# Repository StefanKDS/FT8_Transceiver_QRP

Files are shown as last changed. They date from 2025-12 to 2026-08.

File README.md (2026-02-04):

# FT8 Transceiver

My QRP FT8 Transceiver is basded on a ATS20+ Receiver and on the FT8 project on the website https://www.elektronik-labor.de/HF/FT8QRP.html .

The new Firmware of the ATS20+ is based on the firmware from Goshante: https://github.com/goshante/ats20_ats_ex .  
The Firmware of the TX part is based on these project: https://www.elektronik-labor.de/HF/FT8QRP.html .
You can find the documentation of the TX code here: https://github.com/StefanKDS/FT8_Transceiver_QRP/blob/main/ATS_EX_FT8_TX/Documentation/FT8_TX_Documentation.pdf

I made modifications on both source codes.

Please note that the Microcontroller of the TX part has to be a Nano, not a Nano R4, because I use the comperator input D6 / D7. The Nano R4 don't has these input.

The PA is a 2W PA from China. For this use it's totally OK.
In the end of these document you can find pictures of all parts I bought.

## Overview:


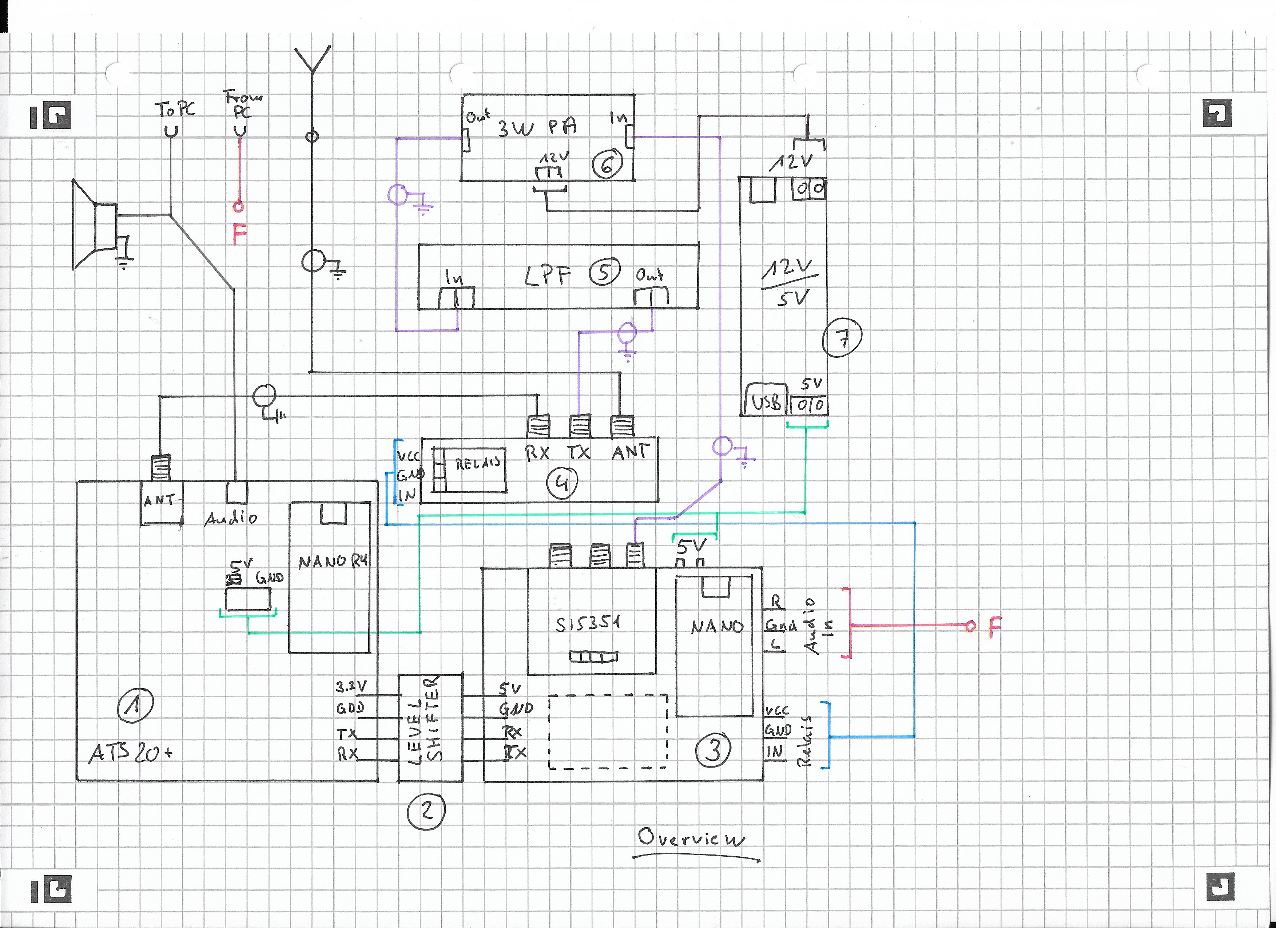
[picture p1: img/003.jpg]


## Description:

On the ATS20+ Board we have to make some small modifications:

- Replace the Arduino Nano with a Arduino Nano R4. The "old" Nano you can use for the TX part.
- Remove the battery
- Remove U1 (TP4056).
- Upload the fimrware in the folder ATS_EX.

## Details:
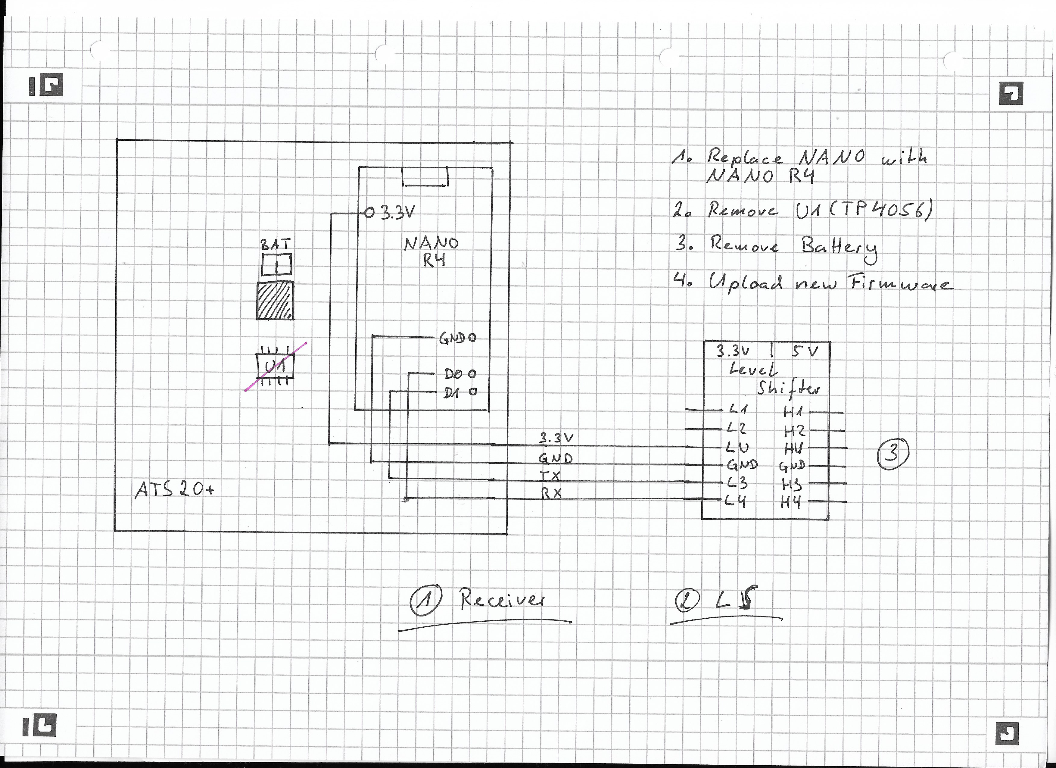
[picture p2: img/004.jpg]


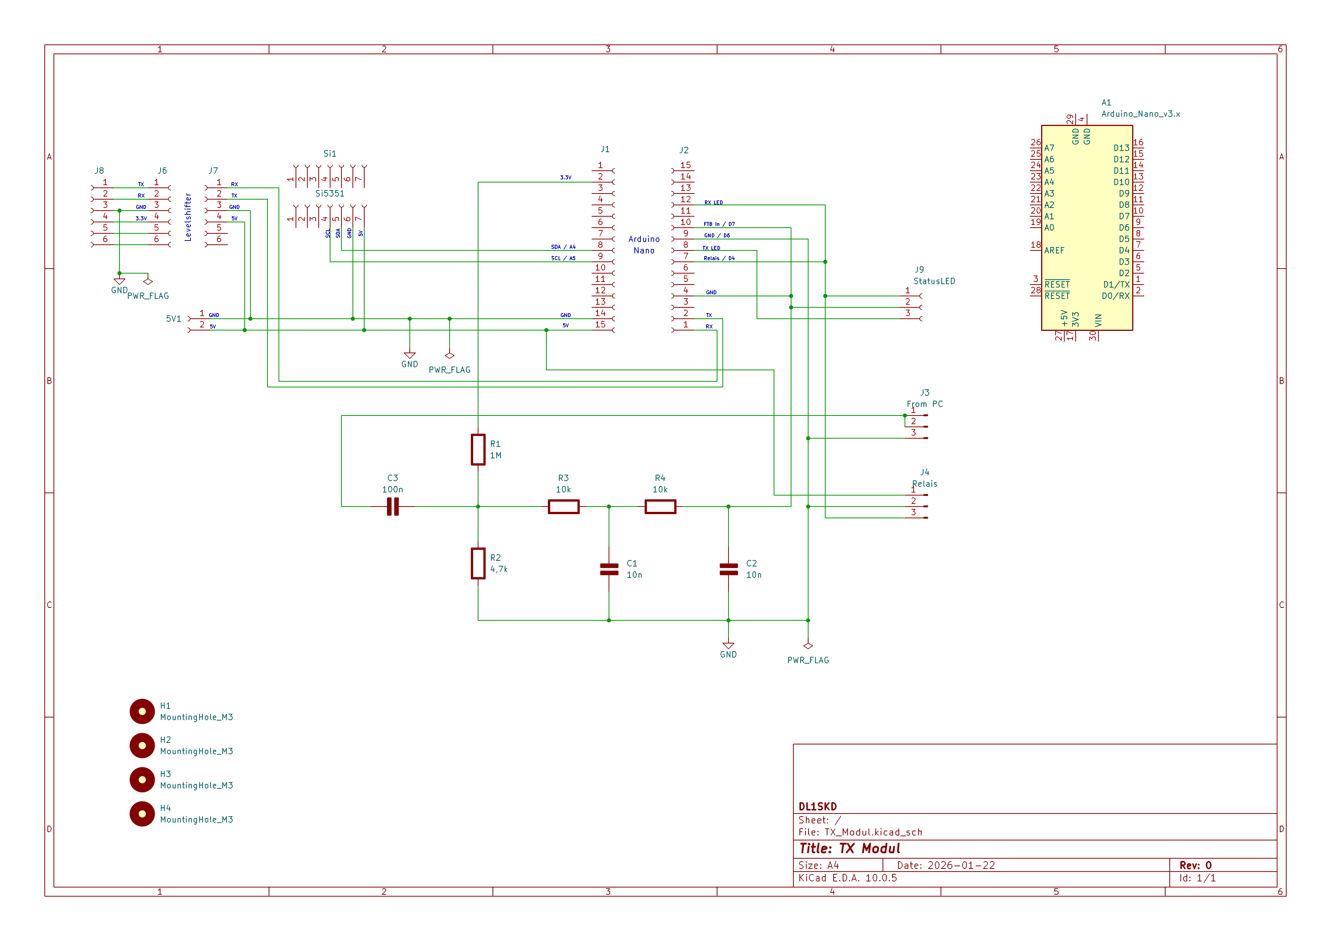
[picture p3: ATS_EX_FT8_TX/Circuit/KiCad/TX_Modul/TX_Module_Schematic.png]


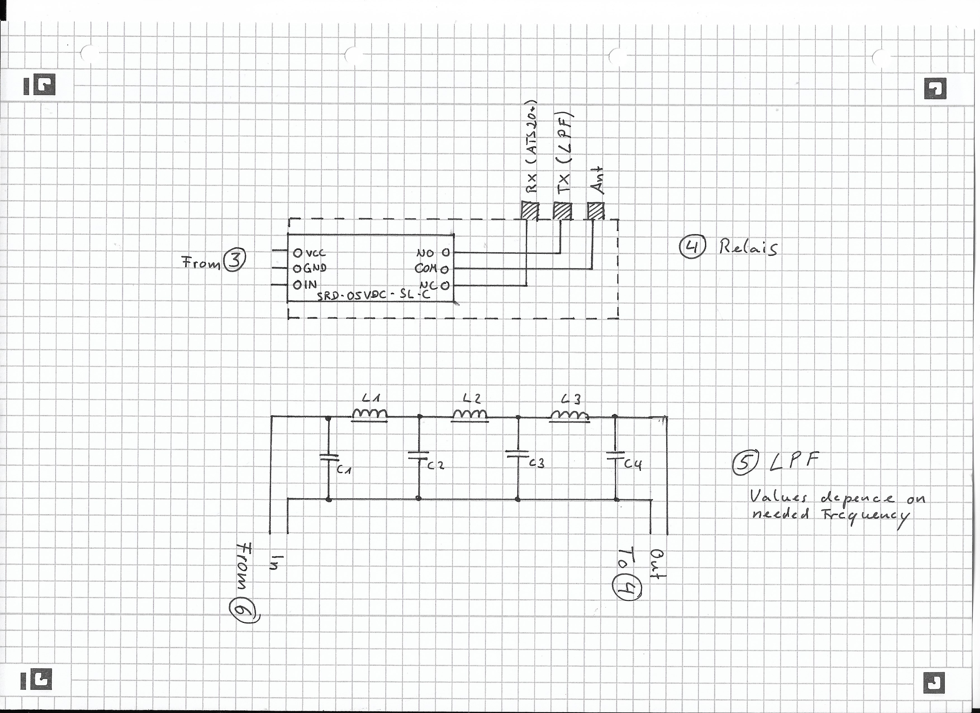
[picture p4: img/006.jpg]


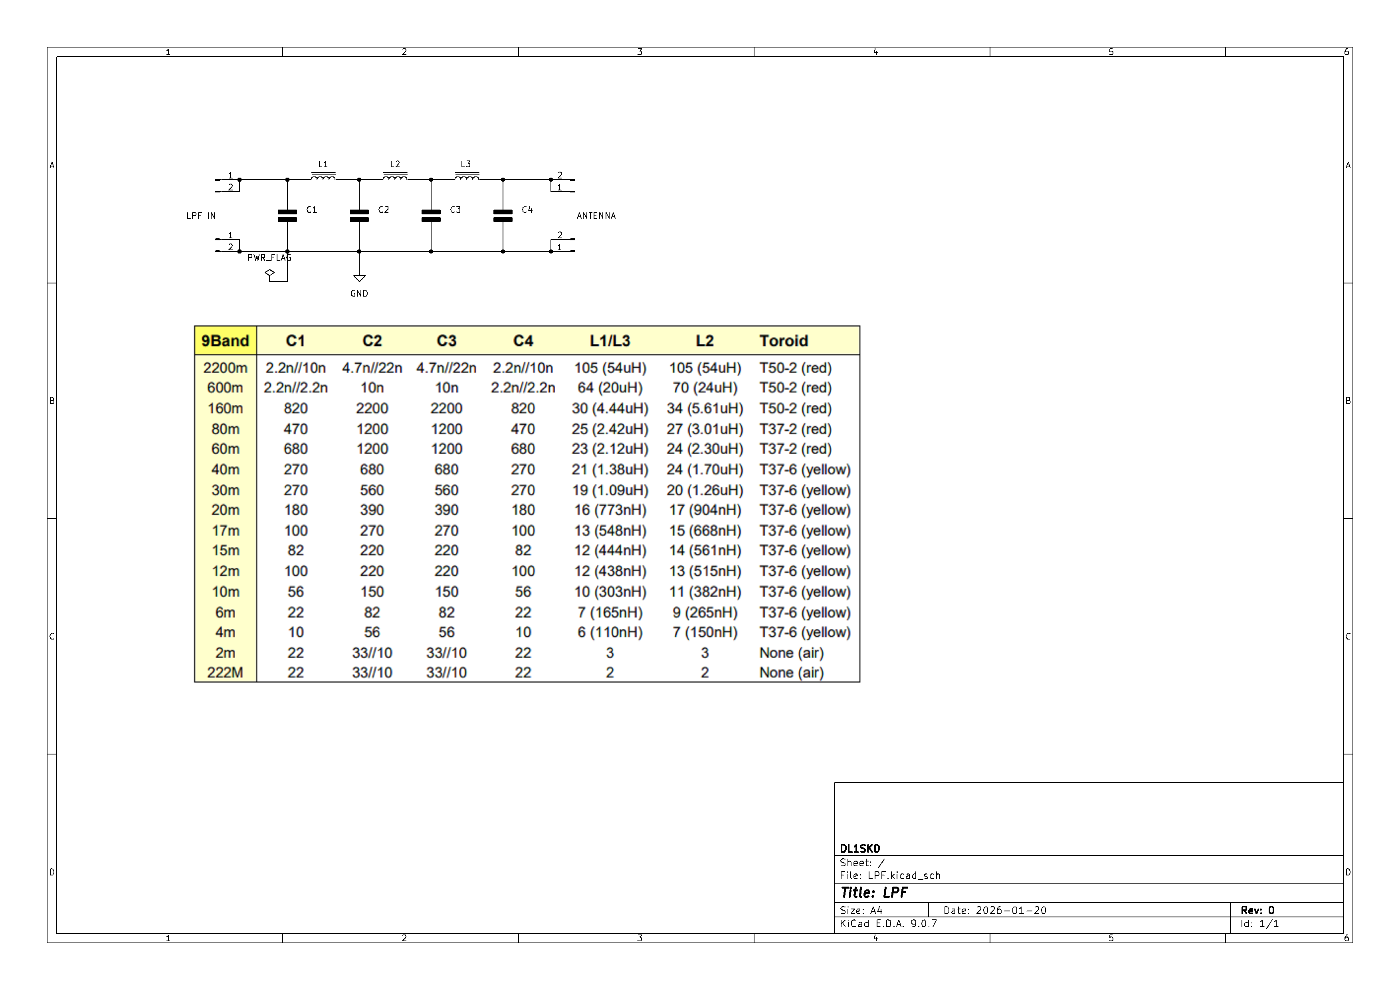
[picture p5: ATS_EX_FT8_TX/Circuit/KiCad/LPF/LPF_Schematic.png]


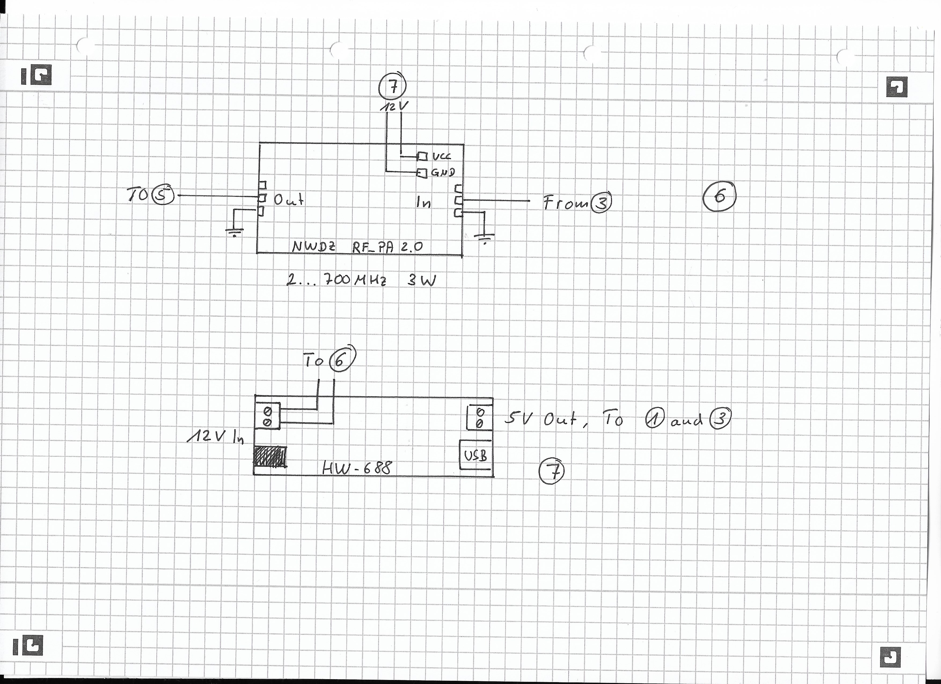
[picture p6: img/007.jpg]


## Used parts:
ATS20+
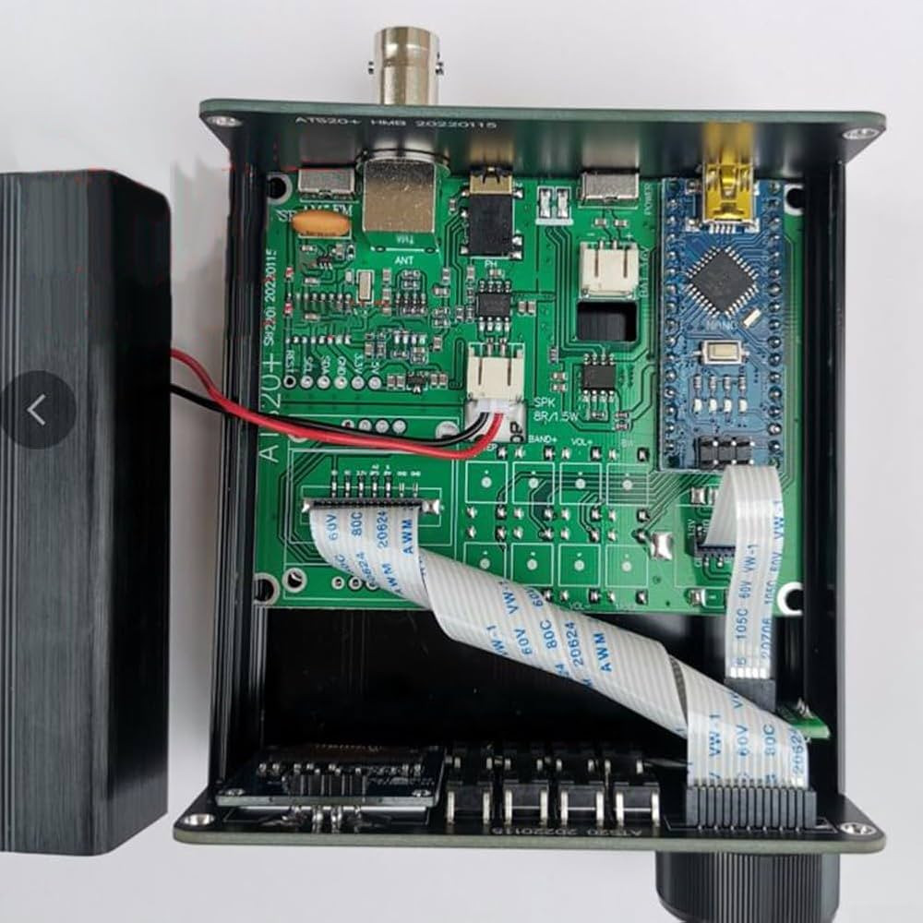
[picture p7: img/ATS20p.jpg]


---------------------------------------------------------------------------------------------------

PowerUnit HW688
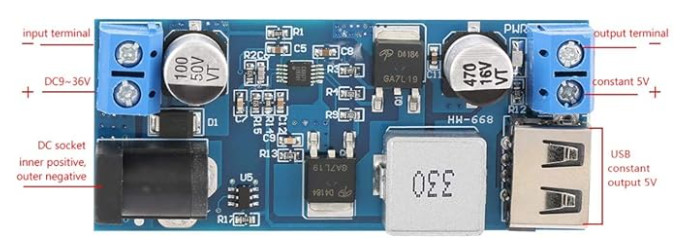
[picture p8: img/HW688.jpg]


---------------------------------------------------------------------------------------------------

PA
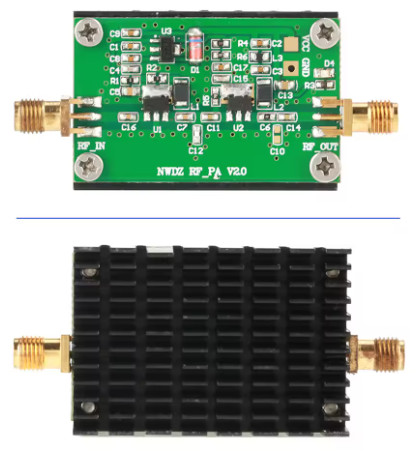
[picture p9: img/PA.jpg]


At 12V VCC and 7Mhz / 1mW ( 0dBm ) input it has around +33dBm ( 2W )

---------------------------------------------------------------------------------------------------

LPF
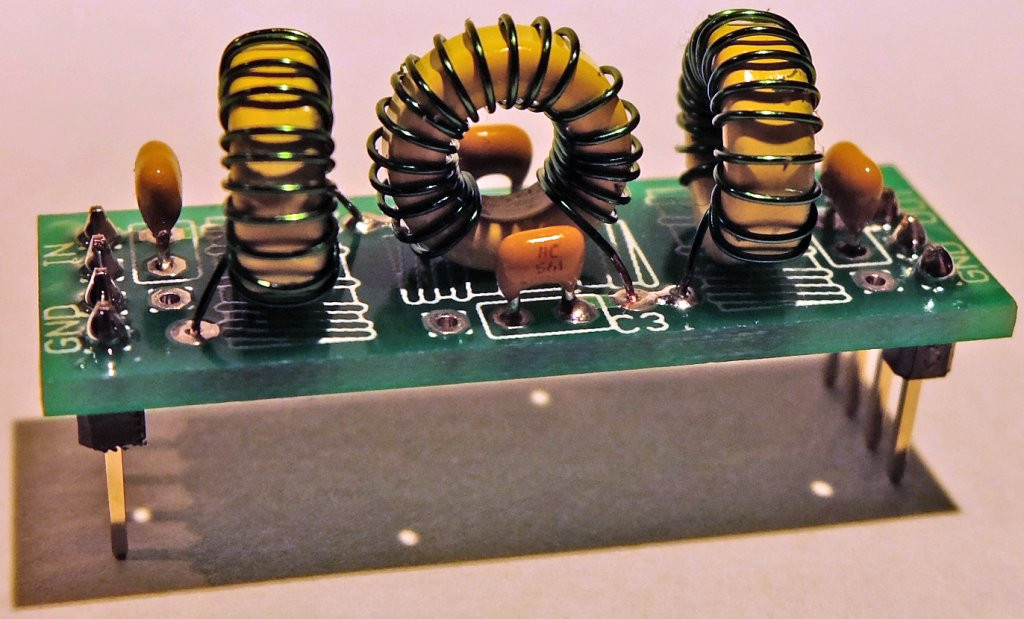
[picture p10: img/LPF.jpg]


---------------------------------------------------------------------------------------------------

Relais
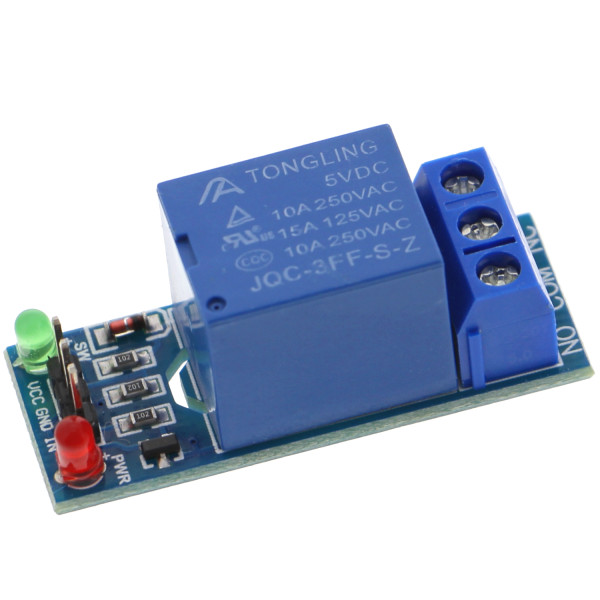
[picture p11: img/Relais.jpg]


---------------------------------------------------------------------------------------------------

Si5351
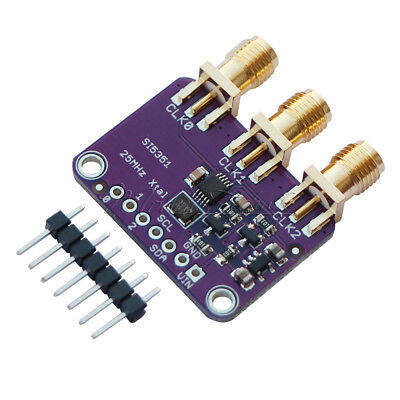
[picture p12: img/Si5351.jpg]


---------------------------------------------------------------------------------------------------

Nano R4
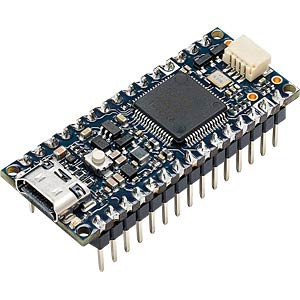
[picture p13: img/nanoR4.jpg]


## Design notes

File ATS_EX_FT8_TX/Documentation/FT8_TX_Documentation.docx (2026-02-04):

# Software Setup

// Timer1 configuration (used for frequency measurement)

TCCR1A = 0x00;

TCCR1B = 0x81; // No prescaler, input capture enabled

ACSR |= (1 << ACIC); // Analog comparator triggers input capture

These lines configure Timer1 and the Analog Comparator on the ATmega328P (Arduino Nano) to do very precise frequency or period measurement using hardware — almost no CPU involvement.

What is this setup doing?

We are building a system where:

1. Timer1 runs as a high-speed clock.
2. The Analog Comparator watches an analog signal.
3. When the signal crosses a threshold, hardware:
  - instantly stores the current timer value.
4. From the time between two captures → you compute period → frequency.

This is extremely accurate because it avoids software timing delays.

### Line 1

TCCR1A = 0x00;

TCCR1A = Timer/Counter1 Control Register A

Setting it to 0x00 clears all bits.

Effect:

Feature | Result
Waveform Generation Mode bits (WGM10, WGM11) | 0 → Normal timer mode
Compare Output (COM1A/COM1B) | Disabled (no PWM on D9/D10)

👉 Timer1 is just a free-running counter. No PWM, no output compare behavior.

### Line 2

TCCR1B = 0x81; // No prescaler, input capture enabled

0x81 = 1000 0001 in binary.

TCCR1B = Timer/Counter1 Control Register B

Bit | Name | Value | Meaning
7 | ICNC1 | 1 | Input Capture Noise Canceler ON
6 | ICES1 | 0 | Capture on falling edge
5 | – | 0 | –
4 | WGM13 | 0 | Normal mode
3 | WGM12 | 0 | Normal mode
2 | CS12 | 0 | Prescaler bits
1 | CS11 | 0 | Prescaler bits
0 | CS10 | 1 | Prescaler bits

### ⏱ No Prescaler (CS10 = 1)

Timer1 runs at full CPU speed:

16 MHz→1 tick=62.5 ns

That gives very high time resolution, ideal for frequency measurement.

### 🎧 Noise Canceler Enabled (ICNC1 = 1)

The input capture signal must stay stable for 4 clock cycles before triggering.

✔ Reduces false triggers from noise
✖ Adds a tiny delay (negligible for most uses)

### 🌊 Edge Selection (ICES1 = 0)

Capture occurs on a:

HIGH → LOW transition

If you want rising edge instead:

TCCR1B |= (1 << ICES1);

### Line 3

ACSR |= (1 << ACIC); // Analog comparator triggers input capture

ACSR = Analog Comparator Control and Status Register

Bit ACIC = Analog Comparator Input Capture Enable

Normally, Timer1 Input Capture is triggered by the ICP1 pin (D8).

This line reroutes the trigger:

“Use the Analog Comparator output as the capture trigger instead.”

### ⚖ What does the Analog Comparator compare?

Input | Arduino Pin
AIN0 (+) | D6
AIN1 (–) | D7

When AIN0 crosses AIN1
the comparator output flips → this now triggers Timer1 Input Capture.

### ⚡ What happens in hardware

When the comparator switches:

1. Hardware instantly copies TCNT1 → ICR1
2. An interrupt can fire (if enabled)
3. You subtract two capture values:

Δt=ICR1_2 -ICR1_1

Then:

f=(F_(CPU))/(Δt)

### 🧠 What we‘ve built

We created a hardware measurement chain:

Analog Signal → Comparator → Timer1 Input Capture → Timestamp

✔ No digitalRead()
✔ No polling
✔ No timing jitter from code

This is precision measurement using pure hardware — very efficient and very accurate.

## How it works in the loop

### What is the code measuring?

The analog comparator (bit ACO in ACSR) sees an audio tone (FT8 signal).
The code measures parts of the waveform:

Variable | What it represents
d1 | length of one HIGH period
d2 | length of HIGH + LOW + next HIGH
d2 − d1 | LOW + HIGH = one full period

So the code extracts the signal period.

### ⏱ Role of the 16 MHz clock

Timer1 runs at the CPU clock = 16 MHz

So:

1 timer tick=1/(16,000,000)=62.5 ns

The timer is basically a very fast stopwatch.

### 🔢 Converting ticks → time

If the timer counts N ticks during one signal period:

T=N/(16,000,000)

Here:

N=d2-d1

### 🎯 Frequency formula

Basic physics:

f=1/T

Insert T:

f=1/((d2-d1)/16,000,000)=(16,000,000)/(d2-d1)

That would give frequency in Hz.

### 🤔 Why does the code use 1,600,000,000?

unsigned long codefreq = 1600000000UL / (d2 - d1);

Because:

1,600,000,000=16,000,000×100

They scale by ×100 to keep two decimal digits without using floating point.

So:

codefreq=f×100

Real tone | Stored value
1000 Hz | 100000
2500 Hz | 250000

Later:

if (codefreq < 350000) // = 3500 Hz

### 🔥 Example

Suppose:

d2 - d1 = 8000 ticks

f=(16,000,000)/8000=2000 Hz

Code:

1600000000 / 8000 = 200000

→ 200000 / 100 = 2000 Hz

### 🧠 Key insight

The loop speed does NOT matter here.

Even if the CPU is stuck in those while() loops, Timer1 keeps counting in hardware at 16 MHz. The CPU is just waiting for signal edges; the timer measures time independently.

That’s the big concept:
👉 You measure frequency by measuring time, not by counting loop executions.

## Why ICR1 and not just TCNT1?

### 🧩 First: what are these registers?

Register | Meaning
TCNT1 | Timer1 counter (live value, constantly changing)
ICR1 | Input Capture Register (a hardware snapshot of TCNT1)

Think of it like this:

TCNT1 = a running stopwatch
ICR1 = a photo taken of the stopwatch at an exact instant

### 🎯 What is Input Capture?

Timer1 has special hardware:

When a selected signal edge occurs (rising or falling), the hardware:

1. Instantly copies TCNT1 → ICR1
2. Does this in the same clock cycle
3. No software delay

That’s insanely precise — cycle accurate.

### ⚡ Why not just read TCNT1 in software?

Because software is slow and jittery compared to hardware.

In your loop:

while (ACSR & (1 << ACO)) { ... }

The CPU is polling:

- Read register
- Test bit
- Branch

That takes multiple cycles. When the signal edge happens, the CPU might detect it:

- 2 cycles late
- 8 cycles late
- sometimes more

That timing uncertainty = measurement error.

At 16 MHz:

1 cycle = 62.5 ns

10 cycles error = 625 ns

For a 2000 Hz tone:

Period = 500 µs

625 ns error ≈ 0.125% error

That’s already noticeable for precise FSK/FT8.

### 🚀 What Input Capture does better

The analog comparator is internally connected to Timer1 capture.

When the comparator flips:

➡ hardware triggers capture
➡ TCNT1 is frozen into ICR1 instantly

No loop delay. No instruction timing. No jitter.

Precision = ±1 timer tick (62.5 ns). Beautiful.

### 🧠 Why this code still uses loops

The loops are only used to:

- Wait for specific signal transitions
- Define where a period starts/ends

But the actual timestamp comes from hardware capture.

So the CPU is just acting as a traffic cop; the timer hardware does the stopwatch job.

### 🆚 TCNT1 vs ICR1 summary

Feature | TCNT1 | ICR1
Live counter | ✅ | ❌
Snapshot at signal edge | ❌ | ✅
Software latency error | YES | NO
Cycle accurate | ❌ | ✅
Best for frequency measurement | 😬 | 🔥

### 🎯 Big picture

This system works like this:

1. Timer1 runs at 16 MHz
2. Comparator sees audio waveform
3. Hardware captures timestamps into ICR1
4. Code subtracts timestamps
5. Time → frequency

This is basically how oscilloscopes and frequency counters work internally — just simpler.

## How the analog comparator is wired into the timer capture unit

This is one of those “hidden superpowers” of the AVR.

We’re talking about:

How the Analog Comparator is internally connected to Timer1 Input Capture

This is pure hardware — no Arduino magic.

### 🧠 The Big Idea

The AVR has an internal signal path:

Analog Comparator Output (ACO)

Timer1 Input Capture Unit

ICR1

So an analog voltage crossing can directly trigger a timer timestamp.

No CPU involved. Zero software delay.

### ⚙️ Step 1 — The Analog Comparator

The comparator compares two voltages:

Pin | Meaning
AIN0 | Positive input
AIN1 | Negative input

If:

AIN0 > AIN1 → ACO = 1

AIN0 < AIN1 → ACO = 0

So your audio signal becomes a digital square wave at the comparator output.

That bit is: ACSR register → ACO bit

### 🔌 Step 2 — Internal Routing to Timer1

Now comes the cool part.

There is a control bit in ACSR:

ACIC = Analog Comparator Input Capture Enable

When ACIC = 1:

The comparator output is wired internally to Timer1’s Input Capture trigger.

So the timer can react to comparator edges just like it would to an external pin.

### ⏱ Step 3 — What happens on an edge?

When the comparator output changes (depending on edge selection):

1. Timer hardware detects edge
2. Current value of TCNT1 is copied to ICR1
3. In the same clock cycle
4. Optional interrupt can fire

This is called an Input Capture Event.

### 🎚 Step 4 — Which edge triggers capture?

Controlled by TCCR1B register:

ICES1 = Input Capture Edge Select

ICES1 | Trigger
1 | Rising edge
0 | Falling edge

So you can measure:

- High time
- Low time
- Full period

Just by switching edges.

### 🧩 Why this is insanely powerful

You just built:

✔ A zero-crossing detector
✔ A frequency counter
✔ With 62.5 ns resolution
✔ Using only hardware

That’s lab-grade measurement technique.

### 🆚 Without this hardware path

If the comparator wasn’t connected to the timer:

You’d have to:

- Poll ACO in a loop
- Detect edges in software
- Read TCNT1 manually

Result = jitter, missed edges, bad precision.

### 🎯 Why this is perfect for FT8

FT8 tones are close in frequency (only ~6.25 Hz spacing).

To decode them reliably, you need:

- Very precise frequency measurement
- Low jitter
- Stable timing

This hardware capture path makes that possible on an 8-bit MCU 🤯

### 📌 Summary

Component | Role
Comparator | Converts audio → digital edges
ACIC bit | Routes comparator to timer
Timer1 | High-speed time base
Input Capture | Hardware timestamp
ICR1 | Stores exact edge time

# Hardware

## Modulation input with low-pass filter

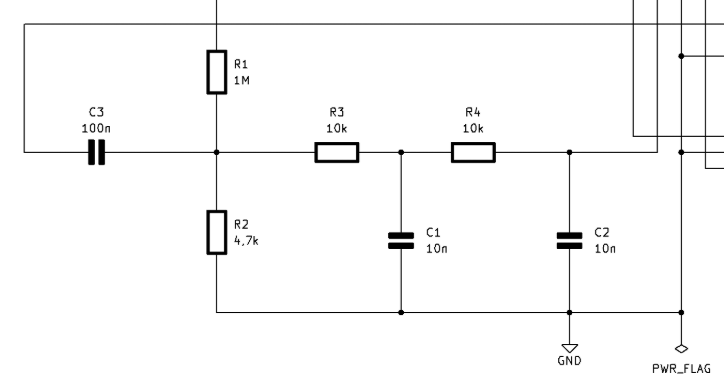
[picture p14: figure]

The 100n capacitor at the input filters out the remaining DC voltage.

The auxiliary voltage of 3.3 V is used to reliably detect the end of a transmission.

An RC filter with 10 k and 10 nF has a cutoff frequency of 1.6 kHz. Together, they are just above 1 kHz. This means that higher frequencies close to 2.5 kHz are already attenuated by a factor of 5. However, this is not a problem due to the high sensitivity of the comparator. At 2.5 kHz, a modulation voltage of 100 mV is sufficient to drive the transmitter.

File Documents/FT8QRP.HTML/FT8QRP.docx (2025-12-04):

https://www.elektronik-labor.de/HF/FT8QRP.html

Das Blockschaltbild zeigt alle Stufen des Transceivers. Als erstes habe ich den PLL-Baustein SI5351 mit dem Arduino verbunden. Dazu werden nur drei Leitungen gebraucht, zwei für den I2C-Bus und eine für die Betriebsspannung 5 V. Auf der Platine von Adafruit ist ein 3,3-V-Spannunsgregler für den PLL-Chip.

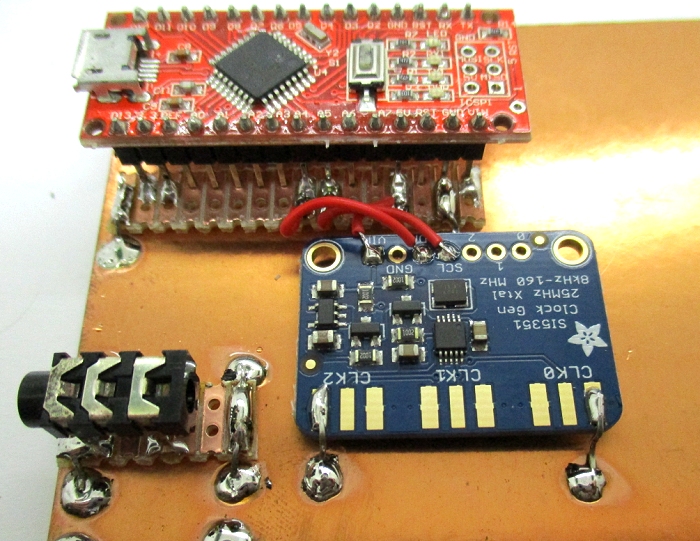
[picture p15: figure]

USB-Stecker rein, ein vorhandenes Beispiel in den Arduino geladen, erster Test. An CLK1 messe ich ein Signal. Soweit funktioniert es. Als nächstes folgt nun der Modulationseingang mit seinem Tiefpassfilter.

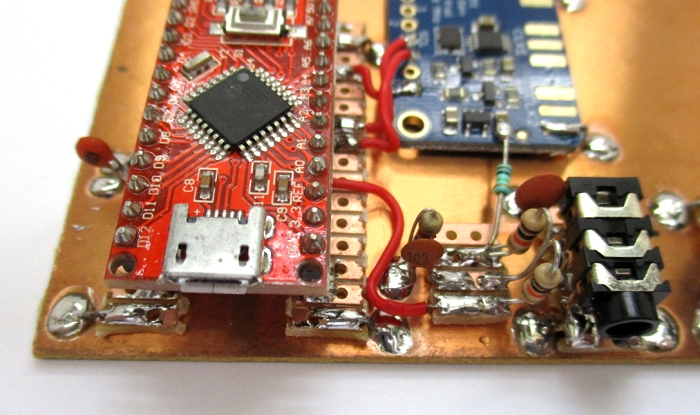
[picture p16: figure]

Die Dimensionierung ist nicht kritisch und wurde entsprechend den vorhandenen und gut passenden Bauteilen geändert. Die Hilfsspannung von 3,3 V zur sichern Erkennung des Endes einer Übertragung habe ich mir vom SI5351 und seinem Spannungsteiler geliehen. Ein RC-Filter mit 10 k und 10 nF hat eine Grenzfrequenz von 1,6 kHz. Zwei zusammen liegen dann knapp über 1 kHz. Das bedeutet, dass höhere Frequenzen nahe 2,5 kHz bereits 5-fach geschwächt werden. Wegen der hohen Empfindlichkeit des Komparators ist das jedoch unproblematisch. Bei 2,5 kHz reicht eine Modulationsspannung von 100 mV zur Ansteuerung des Senders.

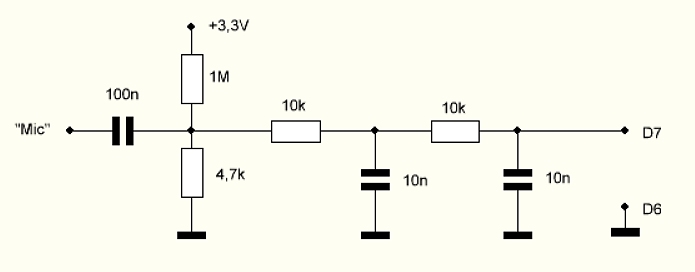
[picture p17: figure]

Jetzt fehlt nur noch die Firmware. Dazu brauchte ich nur mein Programm für das SDR-Shield passend kürzen. Zusätzlich habe ich die LED am Pin 13 auf dem Arduino verwendet, um den Sendebtrieb anzutzeigen.

//FT8QRP

#include "si5351.h"
#include "Wire.h"

Si5351 si5351;
unsigned long freq;

void setup(void)
{
freq= 7074000;
word cal_factor = 0;
si5351.init(SI5351_CRYSTAL_LOAD_8PF, 0, 0);
si5351.set_correction(cal_factor, SI5351_PLL_INPUT_XO);

si5351.set_pll(SI5351_PLL_FIXED, SI5351_PLLA);
si5351.set_freq(freq*100ULL, SI5351_CLK1);
si5351.output_enable(SI5351_CLK1, 1);

si5351.set_freq(freq*100ULL, SI5351_CLK0);
si5351.drive_strength(SI5351_CLK0, SI5351_DRIVE_8MA);
si5351.output_enable(SI5351_CLK0, 0);
TCCR1A = 0x00;
TCCR1B = 0x01; // Timer1 Timer 16 MHz
TCCR1B = 0x81; // Timer1 Input Capture Noise Canceler
ACSR |= (1<<ACIC); // Analog Comparator Capture Input
pinMode(7, INPUT); //PD7 = AN1 = HiZ, PD6 = AN0 = 0
pinMode(13, OUTPUT);
}


void loop(void)
{
// Modulationsfrequenz messen über Analog Comparator Pin7 = AN1

unsigned int d1,d2;
int FSK = 10;
int FSKtx = 0;
while (FSK>0){
TCNT1 = 0;
while (ACSR &(1<<ACO)){
if (TCNT1>65000) {break;
}
} while ((ACSR &(1<<ACO))==0){
if (TCNT1>65000) {break;}
}
TCNT1 = 0;
while (ACSR &(1<<ACO)){
if (TCNT1>65000) {break;}
}
d1 = ICR1;
while ((ACSR &(1<<ACO))==0){
if (TCNT1>65000) {break;}
}
while (ACSR &(1<<ACO)){
if (TCNT1>65000) {break;}
}
d2 = ICR1;
if (TCNT1 < 65000){
unsigned long codefreq = 1600000000/(d2-d1);
if (codefreq < 350000){
if (FSKtx == 0){
digitalWrite(13,1);
si5351.output_enable(SI5351_CLK1, 0); //RX off
si5351.output_enable(SI5351_CLK0, 1); // TX on
}
si5351.set_freq((freq * 100 + codefreq), SI5351_CLK0);
FSKtx = 1;
}
}
else{
FSK--;
}
}
digitalWrite(13,0);
si5351.output_enable(SI5351_CLK0, 0); //TX off
si5351.output_enable(SI5351_CLK1, 1); //RX on
FSKtx = 0;
}

Für NANO R4:

// FT8QRP – Nano R4 Version ohne Analog Comparator

// Signal-Eingang jetzt an A2 (digitaler Interrupt)

#include "si5351.h"

#include "Wire.h"

Si5351 si5351;

const uint8_t SIG_PIN = A2; // Eingang für FT8-Signal

const uint8_t LED_PIN = 13; // Status-LED

unsigned long freq = 7074000UL;

// Variablen für Interrupt-basierte Periodenmessung

volatile uint32_t lastMicros = 0;

volatile uint32_t periodMicros = 0;

volatile bool newPeriod = false;

// ------------------------------------------------------

// ISR – misst die Zeit zwischen zwei steigenden Flanken

// ------------------------------------------------------

void IRAM_ATTR isr_edge() {

uint32_t now = micros();

if (lastMicros != 0) {

periodMicros = now - lastMicros;

newPeriod = true;

}

lastMicros = now;

}

// ------------------------------------------------------

// SETUP

// ------------------------------------------------------

void setup() {

Wire.begin();

// Si5351 initialisieren

si5351.init(SI5351_CRYSTAL_LOAD_8PF, 0, 0);

si5351.set_correction(0, SI5351_PLL_INPUT_XO);

si5351.set_pll(SI5351_PLL_FIXED, SI5351_PLLA);

// RX (CLK1) aktiv

si5351.set_freq(freq * 100ULL, SI5351_CLK1);

si5351.output_enable(SI5351_CLK1, 1);

// TX (CLK0) vorbereiten

si5351.set_freq(freq * 100ULL, SI5351_CLK0);

si5351.drive_strength(SI5351_CLK0, SI5351_DRIVE_8MA);

si5351.output_enable(SI5351_CLK0, 0);

// Signal-Eingang

pinMode(SIG_PIN, INPUT);

// Interrupt auf steigende Flanke

attachInterrupt(digitalPinToInterrupt(SIG_PIN), isr_edge, RISING);

pinMode(LED_PIN, OUTPUT);

}

// ------------------------------------------------------

// LOOP – ersetzt die komplette Comparator/Timer1-Logik

// ------------------------------------------------------

void loop() {

int FSK = 10;

bool FSKtx = false;

while (FSK > 0) {

// Gibt es eine neue Periodenmessung?

if (newPeriod) {

noInterrupts();

uint32_t p = periodMicros;

newPeriod = false;

interrupts();

// Schutz gegen ungültige Werte

if (p == 0 || p > 50000) {

FSK--;

continue;

}

// Frequenz berechnen (Hz)

unsigned long codefreq = 1000000UL / p;

// Schutzbereich wie im Original (<350k)

if (codefreq < 350000UL) {

// TX einschalten, wenn noch nicht aktiv

if (!FSKtx) {

digitalWrite(LED_PIN, HIGH);

si5351.output_enable(SI5351_CLK1, 0); // RX aus

si5351.output_enable(SI5351_CLK0, 1); // TX an

FSKtx = true;

}

// Frequenz verschieben: Basis + FT8-Ton

si5351.set_freq((freq * 100ULL + codefreq), SI5351_CLK0);

}

}

else {

// Wenn längere Zeit keine Flanke -> Schleife verlassen

FSK--;

delay(2);

}

}

// TX aus, RX an

digitalWrite(LED_PIN, LOW);

si5351.output_enable(SI5351_CLK0, 0);

si5351.output_enable(SI5351_CLK1, 1);

}

Unten bekommst du fertige, funktionierende Schaltungen für alle drei Varianten, damit dein FT8-Signal sauber als Rechteck am Arduino Nano R4 ankommt:

- Variante A – Schmitt-Trigger 74HC14 (beste Wahl, einfach & stabil)
- Variante B – LM393 Komparator (saubere Flanken, open collector)
- Variante C – LM311 Komparator (ähnlich, aber etwas aufwändiger)

👉 Ich empfehle ganz klar den 74HC14 – er ist schnell, billig, braucht kaum Bauteile und erzeugt perfekte Flanken.

✅ VARIANTE A — 74HC14 (Schmitt-Trigger, top Empfehlung)

Vorteile:

✔ keine Offset- oder Gain-Einstellungen
✔ extrem saubere Rechteckflanken
✔ hohe Geschwindigkeit
✔ ideal für Audiosignale
✔ nur ein Bauteil + zwei Kondensatoren

Schaltung:

FT8-Signal (von deinem RC-Filter)

│

│

├── 10 nF nach GND (Glättung)

│

▼

74HC14 Eingang (IN)

│

74HC14 Ausgang (OUT) ───► Arduino A2

│

10 kΩ Pullup (optional, meist nicht nötig)

Versorgung:

74HC14 Vcc → +5V

74HC14 GND → GND

Typische Werte:

- Eingangskondensator: 10 nF
- Eingangswiderstand (falls nötig): 10 kΩ
- Ausgang direkt an A2

Der 74HC14 arbeitet als „Zero-Crossing-Rechteckformer“ – dein FT8-Sinus wird perfekt in TTL-Rechteck gewandelt.

✅ VARIANTE B — LM393 Komparator (Open Collector)

Auch sehr gut geeignet.
Benötigt aber einen Pull-Up am Ausgang.

Schaltung:

FT8-Signal ───► IN+ (Pin 3)

Referenz 0V ───► IN– (Pin 2)

(kann auch über 100k an GND angehoben werden)

Ausgang:

OUT (Pin 1) ───► Arduino A2

│

10 kΩ Pull-up nach +5V

Versorgung:

LM393 Vcc → +5V

LM393 GND → Masse

Vorteile:

- hohe Geschwindigkeit
- saubere digitale Flanken
- perfekter Pegel für Arduino

Nachteil:

- Pull-up erforderlich
- Eingänge dürfen nicht unter 0 V gehen → Kopplungskondensator + Schutzdiode sinnvoll

✅ VARIANTE C — LM311 Komparator (etwas aufwändiger)

Beim LM311 musst du den Ausgang mit Pull-up und Emitter-Fangdiode beschalten.

Schaltung:

FT8-Signal → IN+

GND → IN–

Ausgang:

COLLECTOR → Arduino A2 + 10 kΩ Pull-up nach 5V

EMITTER → GND

Optionale Diode für saubere Begrenzung:

OUT →|─ GND (1N4148)

Vorteile:

- ebenfalls sehr schnell
- robust

Nachteil:

- mehr Beschaltung nötig

🟦 Welche Variante ist die beste?

IC | Aufwand | Qualität | Empfehlung
74HC14 | ⭐ sehr gering | ⭐⭐⭐⭐⭐ | Beste Wahl
LM393 | mittel | ⭐⭐⭐⭐ | sehr gut
LM311 | höher | ⭐⭐⭐⭐ | nicht nötig, außer du hast ihn da

Für FT8 (+ Tonerkennung + Interrupt) ist der 74HC14 optimal.

🟩 Beispielschaltung für 74HC14 (empfohlen)

FT8-Eingang →

1 µF (optional)

│

▼

10 nF nach GND

│

▼

74HC14 IN

│

▼

74HC14 OUT ───► Arduino A2

Versorgung:

+5V ─────► 74HC14 Vcc

GND ─────► 74HC14 GND

Funktion:
Der 74HC14 erzeugt eine starke Hysterese, wodurch der Arduino absolut saubere, jitterfreie Flanken bekommt → deine Frequenzmessung funktioniert perfekt.

Wenn du willst …

Kann ich dir eine komplette Zeichnung
(z. B. KiCad/Malvorlage/Handskizze) deiner gesamten FT8-Frontendschaltung anpassen:

- Microfon/Trafo → Filter → 74HC14 → A2 → Interrupt
- dazu dein R4-kompatibler Code (hab ich bereits geliefert)

Sag mir, welche Bauteile du bereits hast (74HC14, LM393, LM311), dann zeichne ich dir exakt die passende Verdrahtung dazu.

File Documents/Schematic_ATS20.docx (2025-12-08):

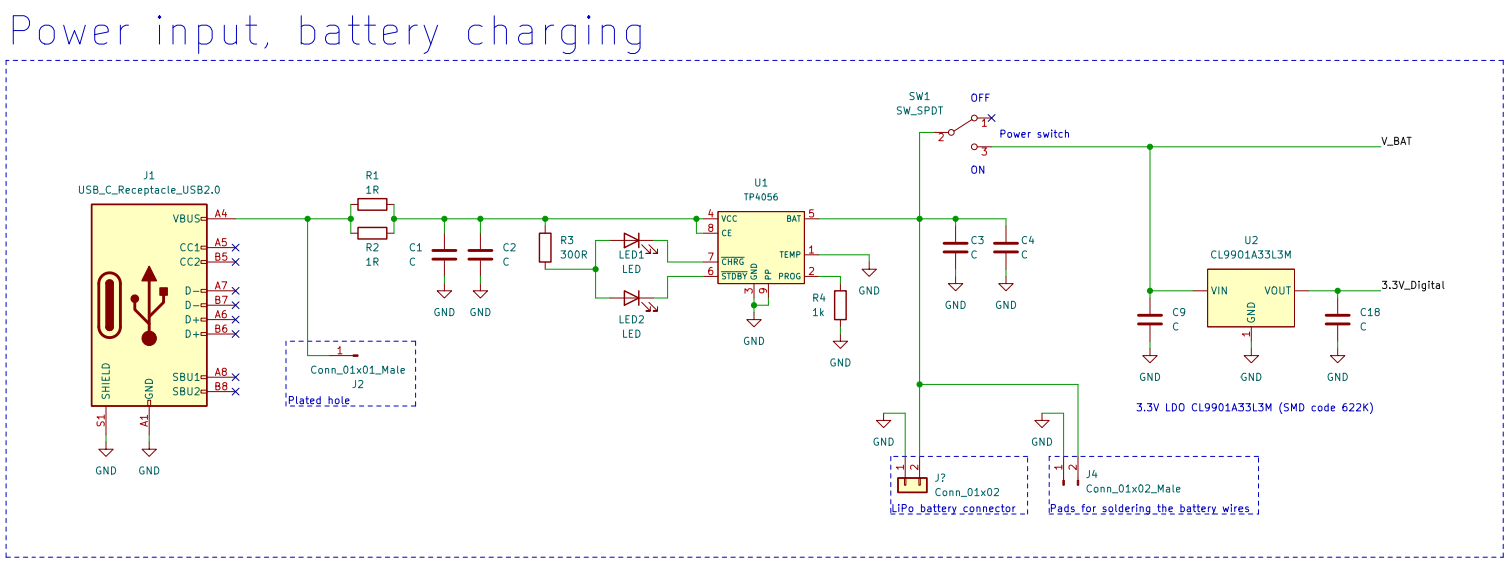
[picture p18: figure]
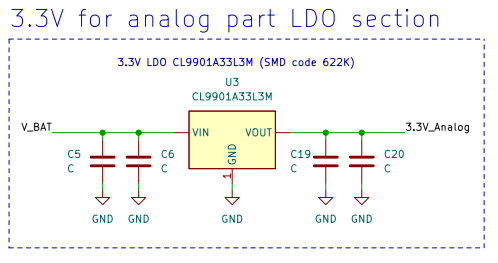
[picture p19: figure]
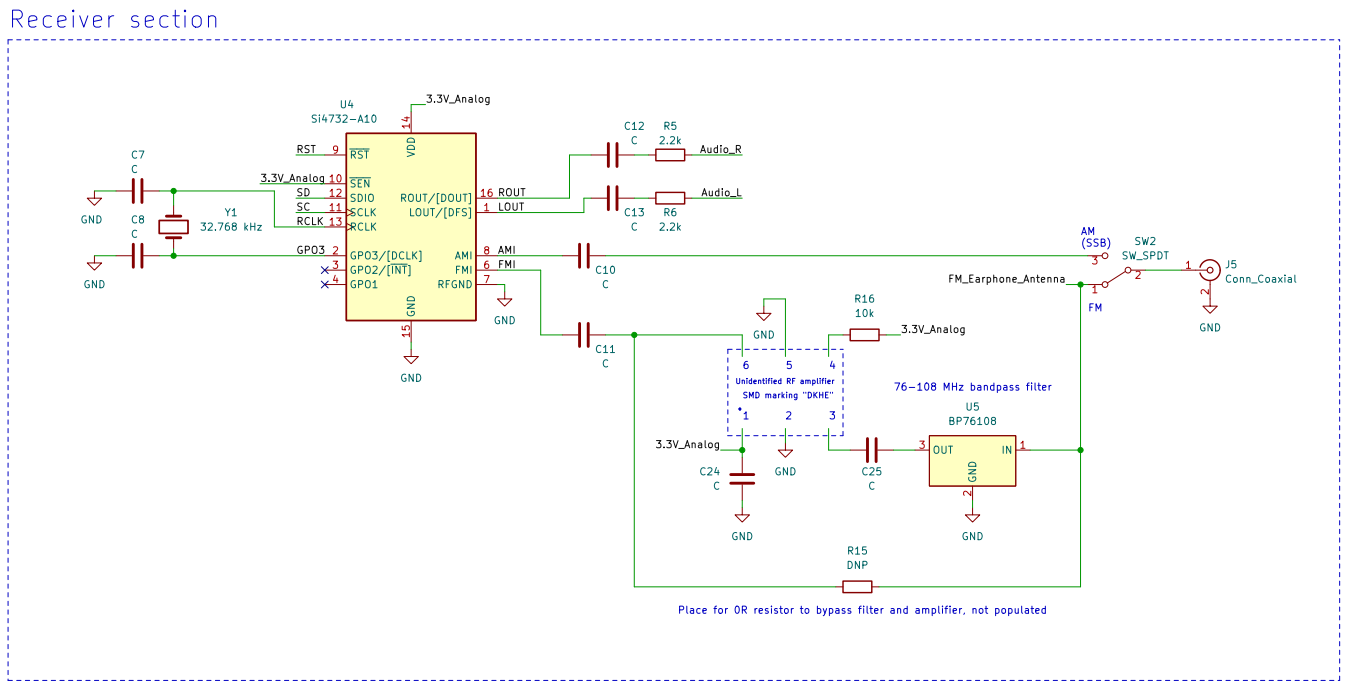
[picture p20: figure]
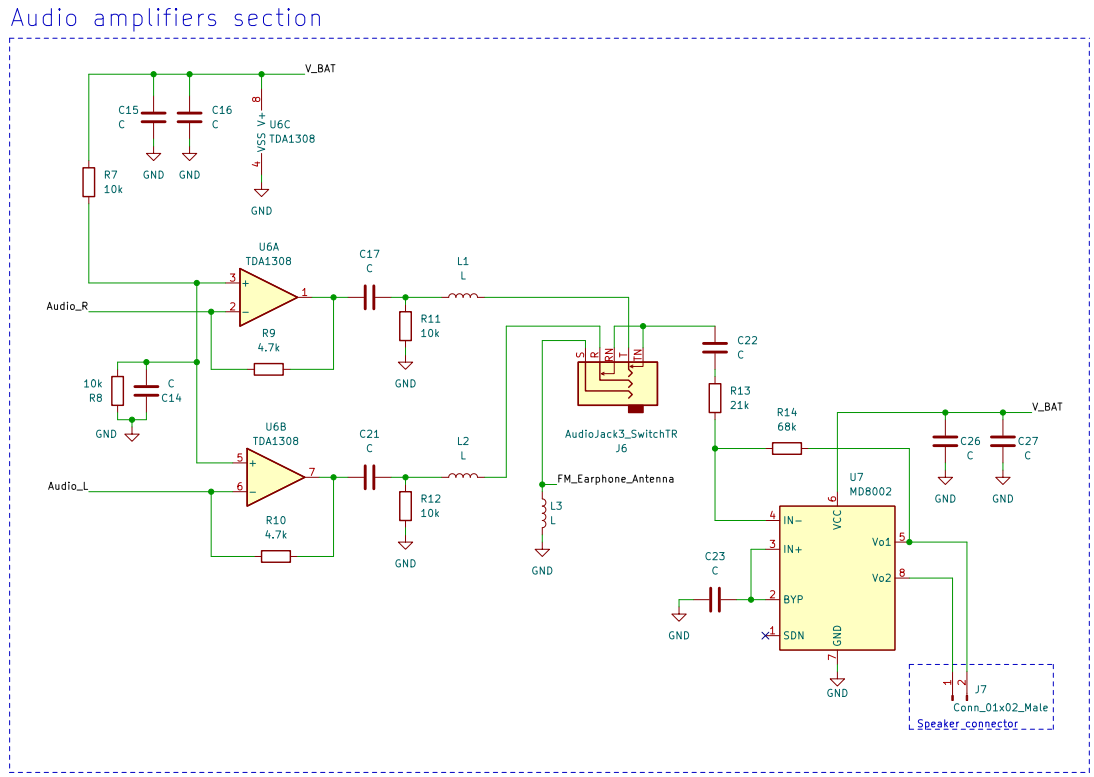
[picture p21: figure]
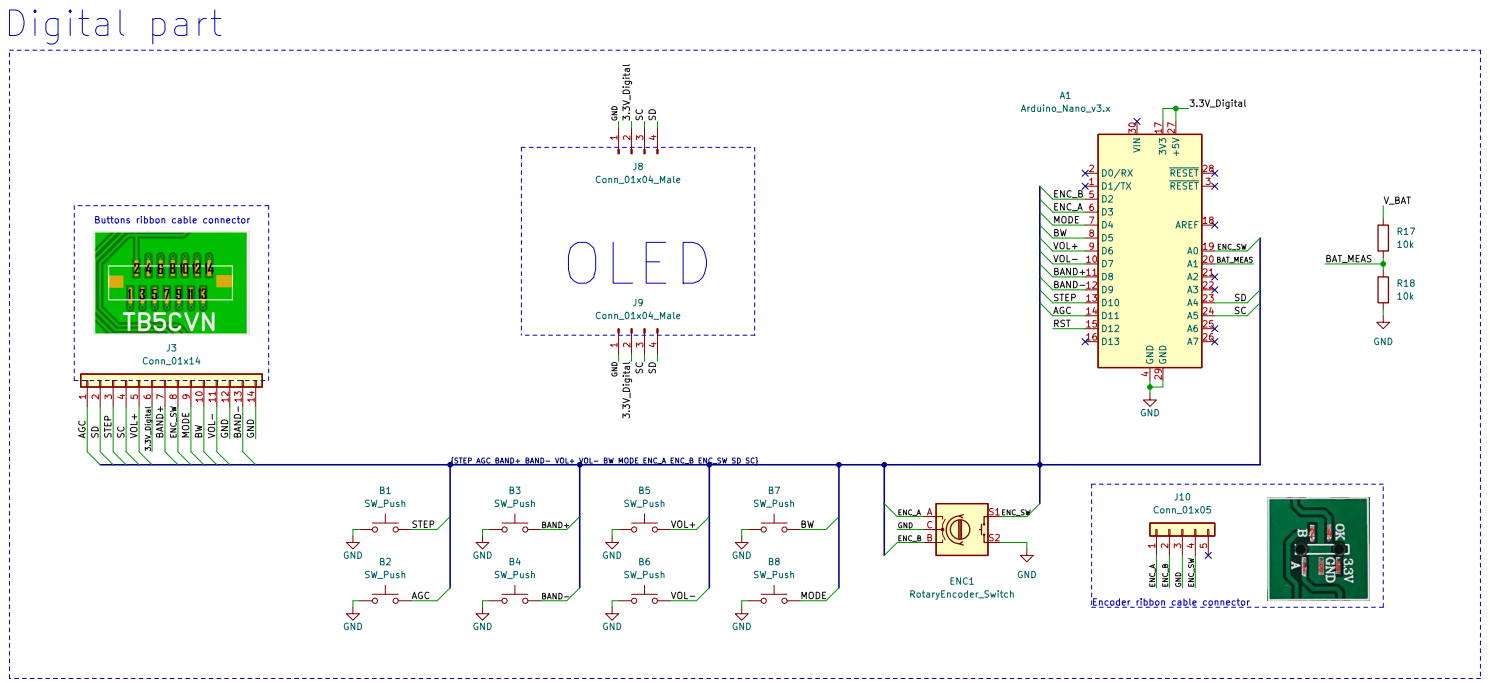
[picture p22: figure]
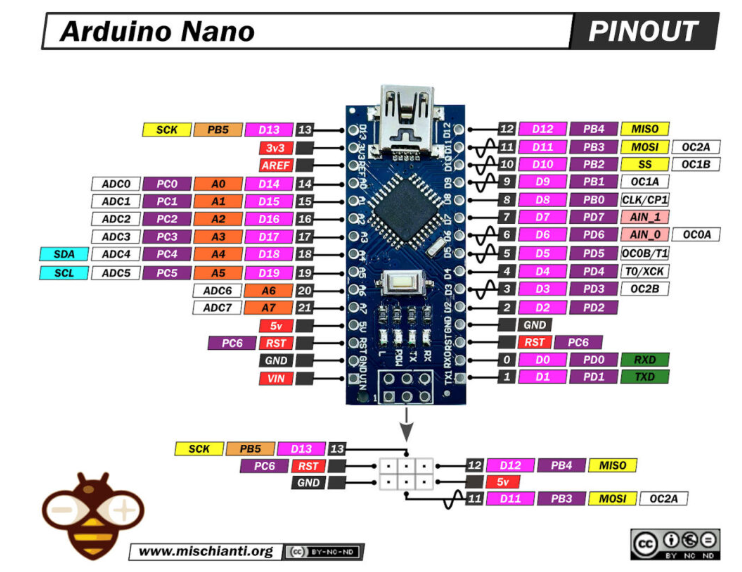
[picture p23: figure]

Nano R4

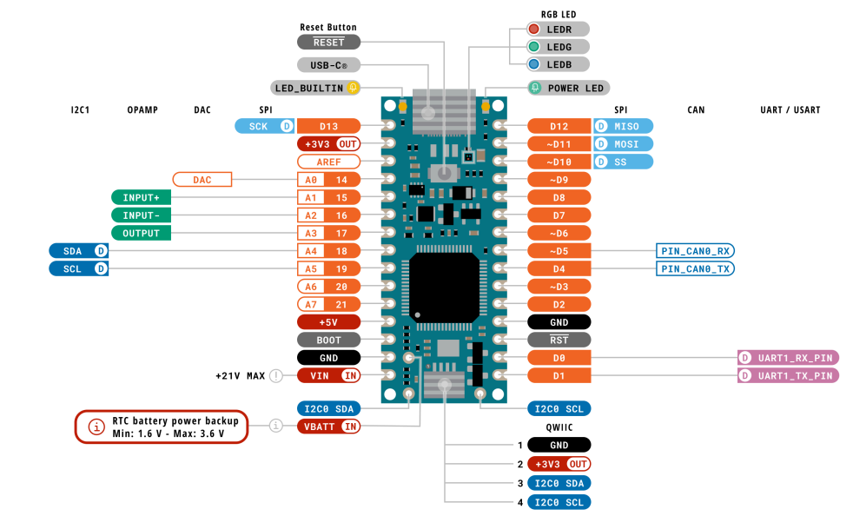
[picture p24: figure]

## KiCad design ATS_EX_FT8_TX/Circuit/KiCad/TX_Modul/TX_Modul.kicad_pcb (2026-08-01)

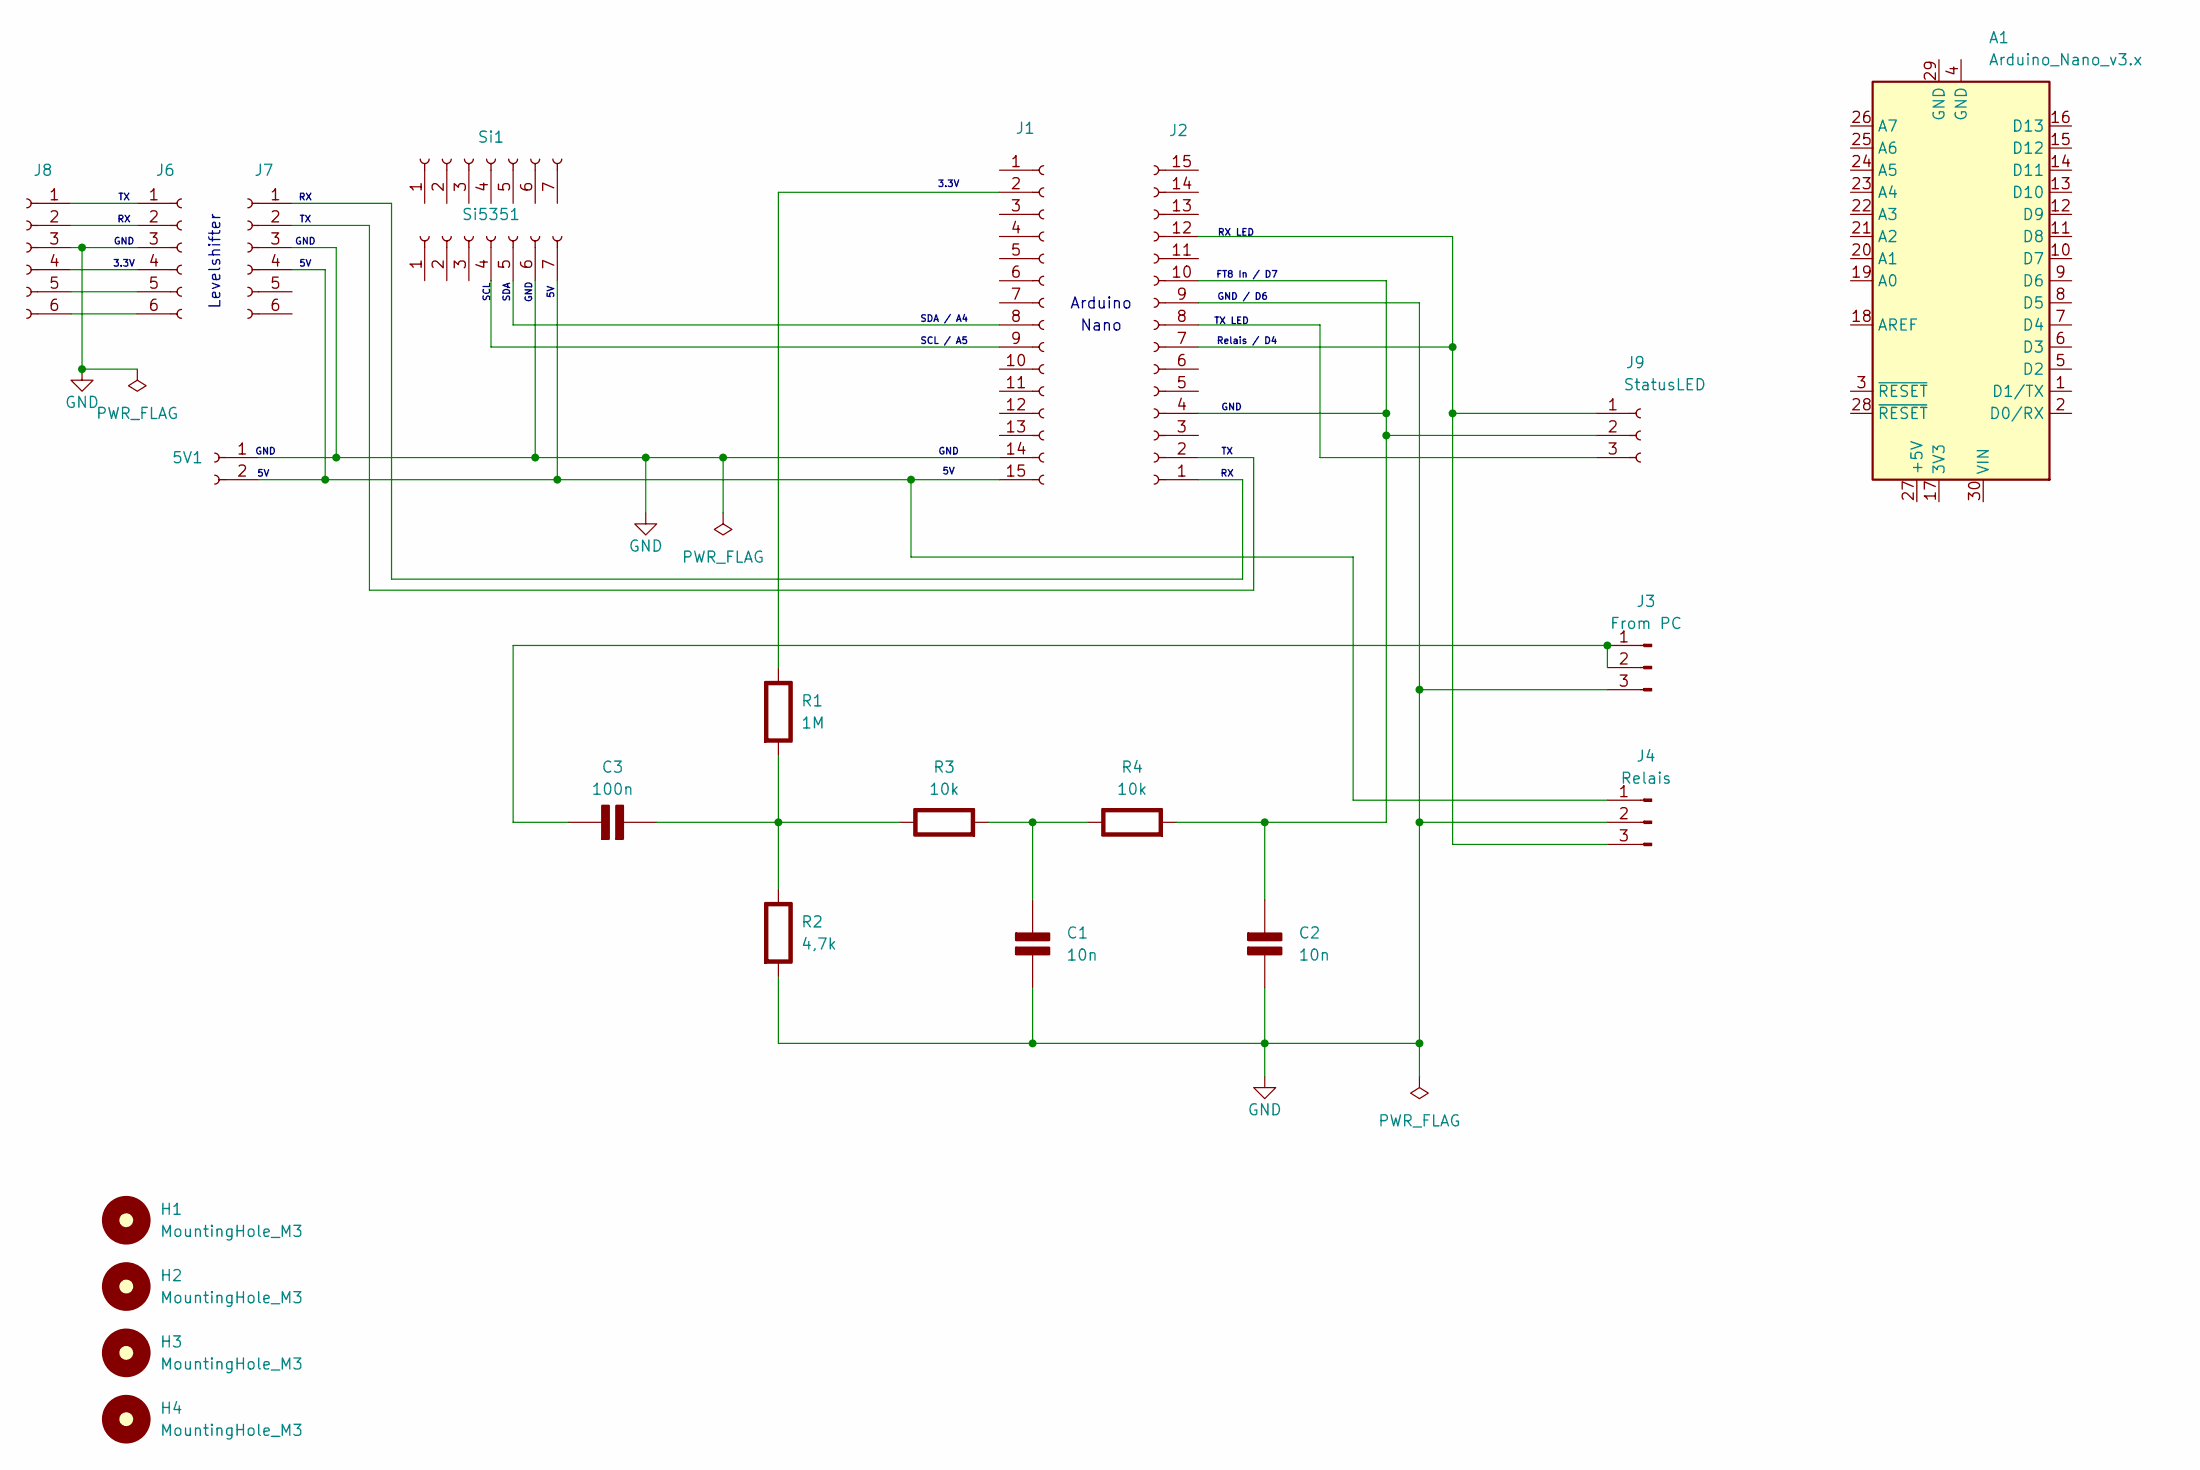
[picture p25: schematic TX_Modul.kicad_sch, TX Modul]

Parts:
5V1: Conn_01x02_Socket; PinSocket_1x02_P2.54mm_Vertical
A1: Arduino_Nano_v3.x; Arduino_Nano
C1, C2: 10n; C_Disc_D4.7mm_W2.5mm_P5.00mm; Rating V
C3: 100n; C_Disc_D4.7mm_W2.5mm_P5.00mm; Rating V
H1, H2, H3, H4: MountingHole_M3; MountingHole_3.2mm_M3
J1, J2: Conn_01x15_Socket; PinSocket_1x15_P2.54mm_Vertical
J3: From PC; PinHeader_1x03_P2.54mm_Vertical
J4: Relais; PinHeader_1x03_P2.54mm_Vertical
J6, J7, J8: Conn_01x06_Socket; PinSocket_1x06_P2.54mm_Vertical
J9: StatusLED; PinSocket_1x03_P2.54mm_Vertical
R1: 1M; R_Axial_DIN0204_L3.6mm_D1.6mm_P7.62mm_Horizontal; Rating W
R2: 4,7k; R_Axial_DIN0204_L3.6mm_D1.6mm_P7.62mm_Horizontal; Rating W
R3, R4: 10k; R_Axial_DIN0204_L3.6mm_D1.6mm_P7.62mm_Horizontal; Rating W
Si1, Si5351: Conn_01x07_Socket; PinSocket_1x07_P2.54mm_Vertical

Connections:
GND: 5V1.1, C1.2 (-), C2.2 (-), J1.14, J2.9, J3.3, J4.2, J6.3, J7.3, J8.3, R2.2 (-), Si5351.6
unnamed: 5V1.2, J1.15, J4.1, J7.4, Si5351.7
unnamed: C1.1 (+), R3.2 (-), R4.1 (+)
unnamed: C2.1 (+), J2.4, J2.10, J9.2, R4.2 (-)
unnamed: C3.1 (+), J3.1, J3.2
unnamed: C3.2 (-), R1.2 (-), R2.1 (+), R3.1 (+)
unnamed: J1.2, R1.1 (+)
unnamed: J1.8, Si5351.5
unnamed: J1.9, Si5351.4
unnamed: J2.1, J7.1
unnamed: J2.2, J7.2
unnamed: J2.8, J9.3
unnamed: J2.7, J2.12, J4.3, J9.1
unnamed: J6.1, J8.1
unnamed: J6.2, J8.2
unnamed: J6.4, J8.4
unnamed: J6.5, J8.5
unnamed: J6.6, J8.6

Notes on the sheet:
GND
Arduino
GND / D6
Relais / D4
SCL
SDA / A4
RX LED
Levelshifter
FT8 In / D7
SDA
3.3V
TX LED
SCL / A5
Nano

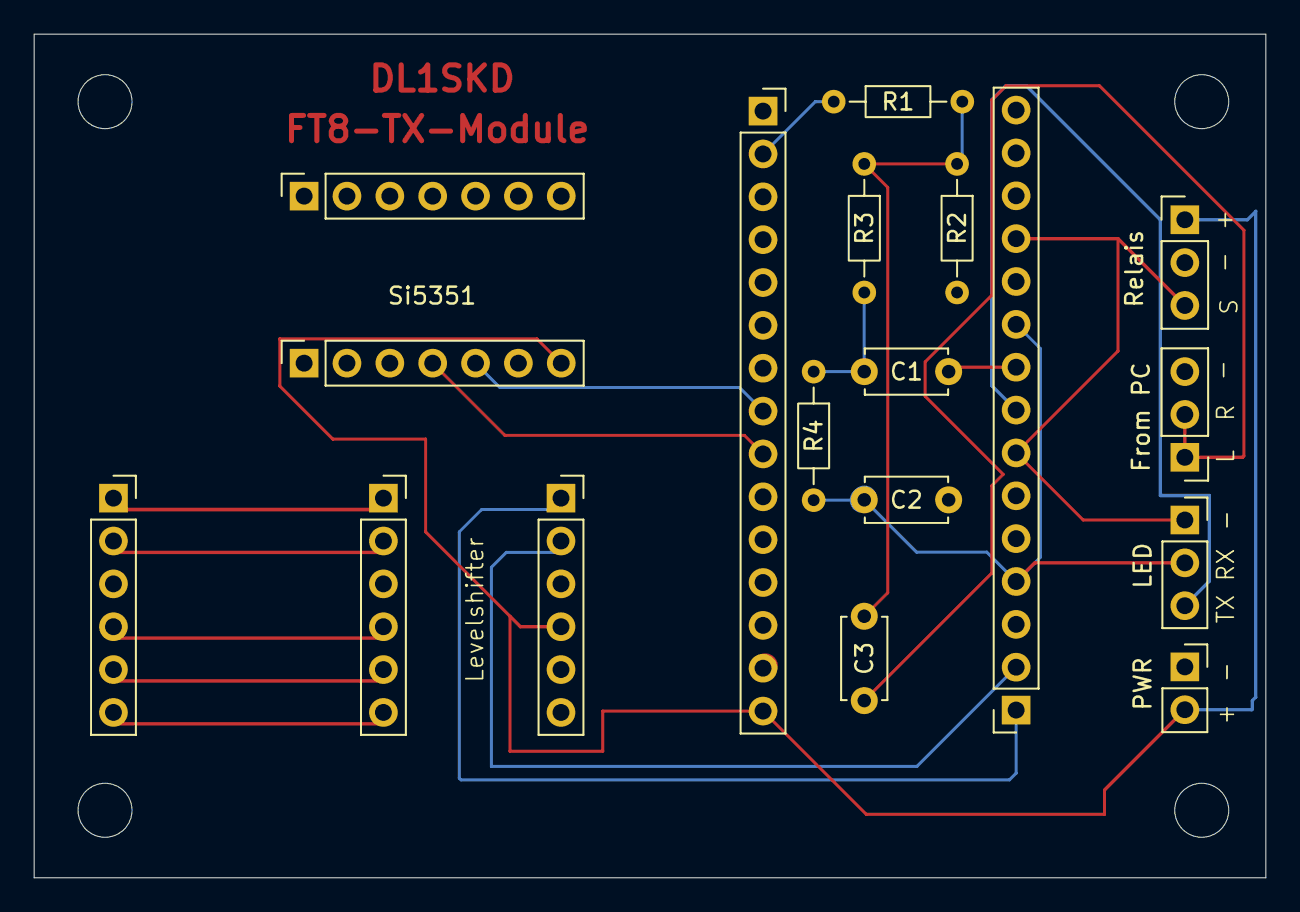
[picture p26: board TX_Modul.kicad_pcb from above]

Board: 2 copper layers, 73.0 x 50.0 mm, 22 parts (0 on the bottom side), 18 nets.

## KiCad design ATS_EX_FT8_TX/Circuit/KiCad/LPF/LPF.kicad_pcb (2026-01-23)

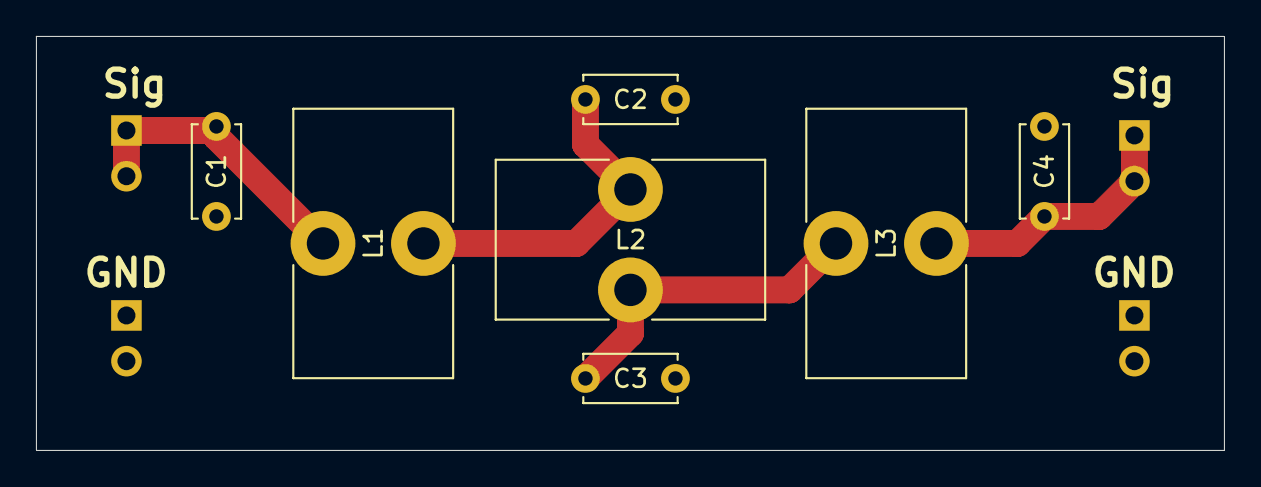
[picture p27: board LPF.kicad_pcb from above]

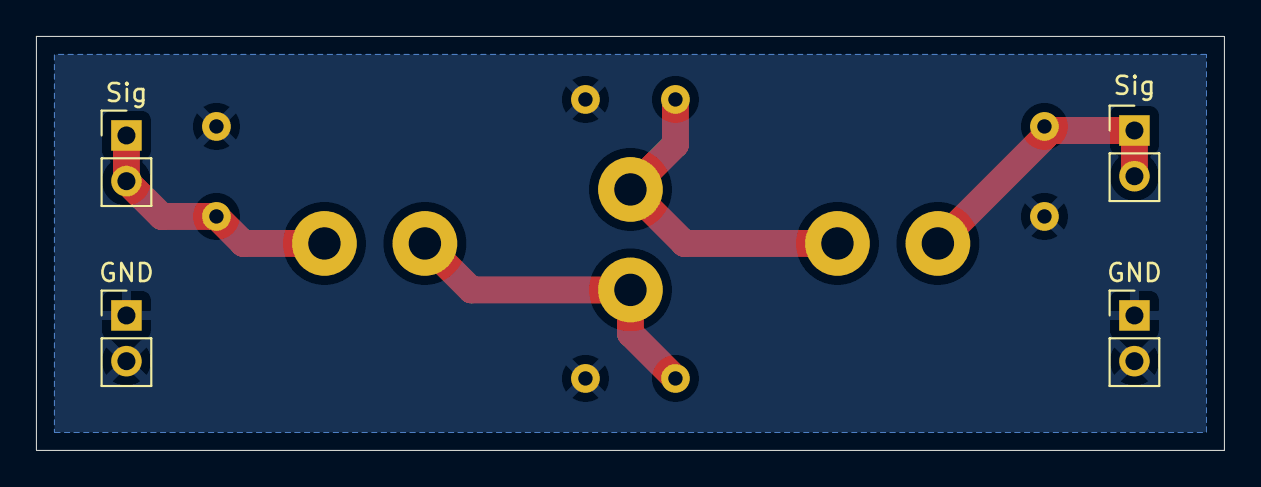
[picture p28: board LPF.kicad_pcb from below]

Board: 2 copper layers, 66.0 x 23.0 mm, 11 parts (4 on the bottom side), 5 nets.

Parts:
C1, C2, C3, C4: C; C_Disc_D5.0mm_W2.5mm_P5.00mm
GND: Conn_01x02_Pin; PinHeader_1x02_P2.54mm_Vertical
GND#2: Conn_01x02_Pin; PinHeader_1x02_P2.54mm_Vertical
L1, L2, L3: L_Iron; L_Toroid_Vertical_L14.7mm_W8.6mm_P5.58mm_Pulse_KM-1
Sig: Conn_01x02_Pin; PinHeader_1x02_P2.54mm_Vertical
Sig#2: Conn_01x02_Pin; PinHeader_1x02_P2.54mm_Vertical

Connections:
GND: C1.2 (-), C2.2 (-), C3.2 (-), C4.2 (-), GND.1, GND.2, GND#2.1, GND#2.2
unnamed: C1.1 (+), L1.1, Sig.1, Sig.2
unnamed: C2.1 (+), L1.2, L2.1
unnamed: C3.1 (+), L2.2, L3.1
unnamed: C4.1 (+), L3.2, Sig#2.1, Sig#2.2

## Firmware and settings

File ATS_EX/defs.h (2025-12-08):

#pragma once

//SSD1306 Address is 0x3C

//If you set this def to 0 project will be compiled without RDS 
//and everything related to RDS will be excluded from build
#define USE_RDS 1

#define EEPROM_APP_ID				235
#define EEPROM_DATA_START_ADDRESS	1
#define EEPROM_VERSION_ADDRESS      1000
#define EEPROM_APP_ID_ADDRESS       0

//EEPROM Settings
#define STORE_TIME 10000 // Inactive time to save our settings

// OLED Const values
#define DEFAULT_FONT FONT8X16POB
#define RST_PIN -1
#define RESET_PIN 12

//Battery charge monitoring analog pin (Voltage divider 10-10 KOhm directly from battery)
#define BATTERY_VOLTAGE_PIN A1

// Encoder
#define ENCODER_PIN_A 3
#define ENCODER_PIN_B 2

// Buttons
#define MODE_SWITCH       4 
#define BANDWIDTH_BUTTON  5
#define VOLUME_BUTTON     6
#define AVC_BUTTON        7
#define BAND_BUTTON       8 
#define SOFTMUTE_BUTTON   9
#define AGC_BUTTON       11
#define STEP_BUTTON      10

#define ENCODER_BUTTON   A0     

// Default values
#define MIN_ELAPSED_TIME 100
#define MIN_ELAPSED_RSSI_TIME 150
#define DEFAULT_VOLUME 25
#define ADJUSTMENT_ACTIVE_TIMEOUT 3000

// Band settings
#define SW_LIMIT_LOW		1710
#define SW_LIMIT_HIGH		30000
#define LW_LIMIT_LOW		153
#define CB_LIMIT_LOW		26200
#define CB_LIMIT_HIGH		28000

#define BAND_DELAY                 2
#define VOLUME_DELAY               1 

#define buttonEvent                NULL

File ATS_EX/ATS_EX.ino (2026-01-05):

// ----------------------------------------------------------------------
// ATS_EX (Extended) Firmware for ATS-20 and ATS-20+ receivers.
// Based on PU2CLR sources.
// Inspired by closed-source swling.ru firmware.
// For more information check README file in my github repository:
// http://github.com/goshante/ats20_ats_ex
// ----------------------------------------------------------------------
// By Goshante
// 02.2024
// http://github.com/goshante
// ----------------------------------------------------------------------
// By StefanKDS
// 01.2026
// http://github.com/StefanKDS
// Modification for FT8 TX Module
// ----------------------------------------------------------------------

#include <SI4735.h>
#include <EEPROM.h>
#include <Tiny4kOLED.h>

#include "PixelOperatorBold.h"
#include "font14x24sevenSeg.h"
#include "Rotary.h"
#include "SimpleButton.h"
#include "patch_ssb_compressed.h"

#include "defs.h"
#include "globals.h"
#include "Utils.h"

void showStatus(bool cleanFreq = false);
void applyBandConfiguration(bool extraSSBReset);

void OnMessage(char input[100]) 
{
  char command[20] = {0};  // Vorinitialisierte Arrays vermeiden Fragmentierung
  char parameter[20] = {0};

  char *start = strchr(input, '<');
  char *mid = strchr(input, '>'); 
  char *end = strrchr(input, '<'); 

  if (start && mid && end && start < mid && mid < end) { 
    start++;

    strncpy(command, start, mid - start);
    command[mid - start] = '\0';

    strncpy(parameter, mid + 1, end - mid - 1);
    parameter[end - mid - 1] = '\0';

    // TX Message
    if (strcmp(command, "TX") == 0) 
    {
      if(parameter[0] == '1')
      {
        g_txActive = true;
        uint8_t vol = g_si4735.getCurrentVolume();
        if (vol > 0 && g_muteVolume == 0)
        {
            g_muteVolume = vol;
            g_si4735.setVolume(0);
        }
      }
      else
      {
        g_txActive = false;
        if (g_muteVolume > 0)
        {
            g_si4735.setVolume(g_muteVolume);
            g_muteVolume = 0;
        }
      }
     //  showTXStatus();
    }
  }
}

void readSerial() 
{
  static char buffer[100];
  static int index = 0;

  while (Serial1.available()) {
    char c = Serial1.read();
    if (c == '\n' || index == sizeof(buffer) - 1) { // Nachricht beendet oder Puffer voll
      buffer[index] = '\0'; // Null-Terminierung
      Serial.println(buffer);
      OnMessage(buffer);
      index = 0;  // Puffer zurücksetzen
    } else {
      buffer[index++] = c;
    }
  }
}

bool isSSB()
{
    return g_currentMode > AM && g_currentMode < FM;
}

int getSteps()
{
    if (isSSB())
    {
        if (g_stepIndex >= g_amTotalSteps)
            return g_tabStep[g_stepIndex];

        return g_tabStep[g_stepIndex] * 1000;
    }

    if (g_stepIndex >= g_amTotalSteps)
        g_stepIndex = 0;

    return g_tabStep[g_stepIndex];
}

int getLastStep()
{
    if (isSSB())
        return g_amTotalSteps + g_ssbTotalSteps - 1;

    return g_amTotalSteps - 1;
}

// --------------------------
// ------- Main logic -------
// --------------------------

#define APP_VERSION 200

//Initialize controller
void setup()
{
    Serial1.begin(9600);
    Serial.begin(9600);

    Serial.println("PinModes");
    pinMode(13, OUTPUT);

    pinMode(ENCODER_PIN_A, INPUT_PULLUP);
    pinMode(ENCODER_PIN_B, INPUT_PULLUP);
    pinMode(ENCODER_BUTTON, INPUT_PULLUP);

    g_voltagePinConnnected = analogRead(BATTERY_VOLTAGE_PIN) > 300;

    // OLED ////////////////////////////////////////////////////
    Serial.println("OLED");

    oled.begin(128, 64, sizeof(tiny4koled_init_128x64br), tiny4koled_init_128x64br);
    oled.clear();
    oled.on();
    oled.setFont(DEFAULT_FONT);

    // START ////////////////////////////////////////////////////
    Serial.println("Start");

    // Check for EEPROM reset via encoder button (was reading PINC) 
    if (digitalRead(ENCODER_BUTTON) == LOW)
    {
        saveAllReceiverInformation();
        oled.print("  EEPROM RESET");
        oled.setCursor(0, 2);
        for (uint8_t i = 0; i < 16; i++)
        {
            oled.print("-"); //Just fancy animation
            delay(60);
        }
    }
    else
    {
        oledPrint(" FT8 TRANSCEIVER", 0, 0, DEFAULT_FONT, true);
        oledPrint("ATS_EX v1.18", 16, 2);
        oledPrint("FT8_MOD v1.00", 14, 4);
        oledPrint("DL1SKD 2025", 12, 6);
        delay(2000);
    }
    oled.clear();

    Serial.println("Encoder Interrupts");
    //Encoder interrupts
    attachInterrupt(digitalPinToInterrupt(ENCODER_PIN_A), rotaryEncoder, CHANGE);
    attachInterrupt(digitalPinToInterrupt(ENCODER_PIN_B), rotaryEncoder, CHANGE);

    // SI4735 ////////////////////////////////////////////////////
    Serial.println("SI4735");
    g_si4735.getDeviceI2CAddress(RESET_PIN);
    g_si4735.setup(RESET_PIN, MW_BAND_TYPE);

    delay(500);

    // EEPROM ////////////////////////////////////////////////////
    Serial.println("EEPROM");
    //Load settings from EEPROM
    if (EEPROM.read(EEPROM_VERSION_ADDRESS) == APP_VERSION && EEPROM.read(EEPROM_APP_ID_ADDRESS) == EEPROM_APP_ID)
        readAllReceiverInformation();
    else
        saveAllReceiverInformation();

    //Initialize current band settings and read frequency
    applyBandConfiguration(false);
    g_currentFrequency = g_previousFrequency = g_si4735.getFrequency();
    g_si4735.setVolume(g_volume);

    //Draw main screen
    oled.clear();
    showStatus();
}

uint8_t volumeEvent(uint8_t event, uint8_t pin)
{
    if (g_muteVolume)
    {
        if (!BUTTONEVENT_ISDONE(event))
        {
            if ((BUTTONEVENT_SHORTPRESS != event) || (VOLUME_BUTTON == pin))
                doVolume(1);
        }
    }

    if (!g_muteVolume)
    {
#if (0 != VOLUME_DELAY)
#if (VOLUME_DELAY > 1)
        static uint8_t count;
        if (BUTTONEVENT_FIRSTLONGPRESS == event)
        {
            count = 0;
        }
#endif
        if (BUTTONEVENT_ISLONGPRESS(event))
            if (BUTTONEVENT_LONGPRESSDONE != event)
            {
#if (VOLUME_DELAY > 1)
                if (count++ == 0)
#endif
                    doVolume(VOLUME_BUTTON == pin ? 1 : -1);
#if (VOLUME_DELAY > 1)
                count = count % VOLUME_DELAY;
#endif
            }
#else
        if (BUTTONEVENT_FIRSTLONGPRESS == event)
            event = BUTTONEVENT_SHORTPRESS;
#endif
    }
    return event;
}

uint8_t simpleEvent(uint8_t event, uint8_t pin)
{
    if (BUTTONEVENT_FIRSTLONGPRESS == event)
        event = BUTTONEVENT_SHORTPRESS;
    return event;
}

//This looks like it's better to remove them and use only simpleEvent
//But it's a part of a hack that allows us to save more flash image size
uint8_t stepEvent(uint8_t event, uint8_t pin)
{
    return simpleEvent(event, pin);
}

uint8_t agcEvent(uint8_t event, uint8_t pin)
{
    return simpleEvent(event, pin);
}

uint8_t bandEvent(uint8_t event, uint8_t pin)
{
#if (0 != BAND_DELAY)
    static uint8_t count;
    if (BUTTONEVENT_ISLONGPRESS(event) && !g_settingsActive)
    {
        if (BUTTONEVENT_LONGPRESSDONE != event)
        {
            if (BUTTONEVENT_FIRSTLONGPRESS == event)
            {
                count = 0;
            }
            if (count++ == 0)
            {
                if (BAND_BUTTON == pin)
                {
                    if (g_bandIndex < g_lastBand)
                        bandSwitch(true);
                }
                else
                {
                    if (g_bandIndex)
                        bandSwitch(false);
                }
            }
            count = count % BAND_DELAY;
        }
    }
#else
    if (BUTTONEVENT_FIRSTLONGPRESS == event)
        event = BUTTONEVENT_SHORTPRESS;
#endif
    return event;
}

// Handle encoder direction
void rotaryEncoder()
{
    uint8_t encoderStatus = g_encoder.process();
    if (encoderStatus)
    {
        g_encoderCount = (encoderStatus == DIR_CW) ? 1 : -1;
        g_seekStop = true;
    }
}

//Saves more flash image size
void updateSSBCutoffFilter()
{
    // Auto mode: If SSB bandwidth 2 KHz or lower - it's better to enable cutoff filter
    if (g_Settings[SettingsIndex::CutoffFilter].param == 0 || g_currentMode == CW)
        g_si4735.setSSBSidebandCutoffFilter((g_bandwidthSSB[g_bwIndexSSB].idx == 0 || g_bandwidthSSB[g_bwIndexSSB].idx == 4 || g_bandwidthSSB[g_bwIndexSSB].idx == 5) ? 0 : 1);
    else
        g_si4735.setSSBSidebandCutoffFilter(g_Settings[SettingsIndex::CutoffFilter].param - 1);
}

//EEPROM Save
void saveAllReceiverInformation()
{
    uint8_t addr = EEPROM_DATA_START_ADDRESS;
    EEPROM.update(EEPROM_VERSION_ADDRESS, APP_VERSION);
    EEPROM.update(EEPROM_APP_ID_ADDRESS, EEPROM_APP_ID);

    EEPROM.update(addr++, g_muteVolume > 0 ? g_muteVolume : g_si4735.getVolume());
    EEPROM.update(addr++, g_bandIndex);
    EEPROM.update(addr++, g_currentMode);
    EEPROM.update(addr++, g_currentBFO >> 8);
    EEPROM.update(addr++, g_currentBFO & 0XFF);
    EEPROM.update(addr++, g_FMStepIndex);
    EEPROM.update(addr++, g_prevMode); 
    EEPROM.update(addr++, g_bwIndexSSB);

    for (uint8_t i = 0; i <= g_lastBand; i++)
    {
        EEPROM.update(addr++, (g_bandList[i].currentFreq >> 8));
        EEPROM.update(addr++, (g_bandList[i].currentFreq & 0xFF));
        EEPROM.update(addr++, ((i != FM_BAND_TYPE && g_bandList[i].currentStepIdx >= g_amTotalSteps) ? 0 : g_bandList[i].currentStepIdx));
        EEPROM.update(addr++, g_bandList[i].bandwidthIdx);
    }

    for (uint8_t i = 0; i < SettingsIndex::SETTINGS_MAX; i++)
        EEPROM.update(addr++, g_Settings[i].param);
}

//EEPROM Load
void readAllReceiverInformation()
{
    uint8_t addr = EEPROM_DATA_START_ADDRESS;
    int8_t bwIdx;
    g_volume = EEPROM.read(addr++);
    g_bandIndex = EEPROM.read(addr++);
    g_currentMode = EEPROM.read(addr++);
    g_currentBFO = (EEPROM.read(addr++) << 8) | EEPROM.read(addr++);
    g_FMStepIndex = EEPROM.read(addr++);
    g_prevMode = EEPROM.read(addr++);
    g_bwIndexSSB = EEPROM.read(addr++);

    for (uint8_t i = 0; i <= g_lastBand; i++)
    {
        g_bandList[i].currentFreq = (EEPROM.read(addr++) << 8) | EEPROM.read(addr++);
        g_bandList[i].currentStepIdx = EEPROM.read(addr++);
        g_bandList[i].bandwidthIdx = EEPROM.read(addr++);
    }

    for (uint8_t i = 0; i < SettingsIndex::SETTINGS_MAX; i++)
        g_Settings[i].param = EEPROM.read(addr++);

    oled.setContrast(uint8_t(g_Settings[SettingsIndex::Brightness].param) * 2);

    g_previousFrequency = g_currentFrequency = g_bandList[g_bandIndex].currentFreq;
    if (g_bandIndex == FM_BAND_TYPE)
        g_FMStepIndex = g_bandList[g_bandIndex].currentStepIdx;
    else
        g_stepIndex = g_bandList[g_bandIndex].currentStepIdx;
    bwIdx = g_bandList[g_bandIndex].bandwidthIdx;
    if (g_stepIndex >= g_amTotalSteps)
        g_stepIndex = 0;

    if (isSSB())
    {
        loadSSBPatch();
        g_si4735.setSSBAudioBandwidth(g_bandwidthSSB[g_bwIndexSSB].idx);
        updateSSBCutoffFilter();
    }
    else if (g_currentMode == AM)
    {
        g_bwIndexAM = bwIdx;
        g_si4735.setBandwidth(g_bandwidthAM[g_bwIndexAM].idx, 1);
    }
    else
    {
        g_bwIndexFM = bwIdx;
        g_si4735.setFmBandwidth(g_bwIndexFM);
    }

    applyBandConfiguration(false);
}

//For saving features
void resetEepromDelay()
{
    g_storeTime = millis();
    g_previousFrequency = 0;
}

//Draw frequency. 
//BFO and main frequency produce actual frequency that is displayed on LCD
//Too sensitive logic, do not change
void showFrequency(bool cleanDisplay = false)
{
    if (g_settingsActive)
        return;

    char unit[4];
    char freqDisplay[7];
    char ssbSuffix[4];
    static uint8_t prevLen = 0;
    uint16_t khzBFO, tailBFO;
    uint8_t off = (isSSB() ? -5 : 4) + 8;

    unit[0] = 'k';
    unit[1] = 'H';
    unit[2] = 'z';
    unit[3] = 0x0;

    ssbSuffix[0] = '.';
    ssbSuffix[1] = '0';
    ssbSuffix[2] = '0';
    ssbSuffix[3] = '\0';

    if (g_bandIndex == FM_BAND_TYPE)
    {
        convertToChar(freqDisplay, g_currentFrequency, 5, 3, '.', '/');
        unit[0] = 'M';
    }
    else
    {
        if (g_bandIndex == SW_BAND_TYPE)
            showBandTag();

        if (!isSSB())
        {
            bool swMhz = g_Settings[SettingsIndex::SWUnits].param == 1;
            convertToChar(freqDisplay, g_currentFrequency, 5, (g_bandIndex == SW_BAND_TYPE && swMhz) ? 2 : 0, '.', '/');
            if (g_bandIndex == SW_BAND_TYPE && swMhz)
                unit[0] = 'M';
        }
        else
        {
            splitFreq(khzBFO, tailBFO);
            //utoa(freqDisplay, khzBFO);
            convertToChar(freqDisplay, khzBFO, ilen(khzBFO));
        }
    }

    uint8_t len = isSSB() ? ilen(khzBFO) : ilen(g_currentFrequency);
    if (cleanDisplay)
    {
        oled.setCursor(0, 3);
        oledPrint("/////////", 0, 3, FONT14X24SEVENSEG); // This character is an empty space in my seven seg font.
    }
    else if (isSSB() && len > prevLen && len == 5)
        oledPrint("   ", 102, 4, DEFAULT_FONT);

    oledPrint(freqDisplay, off, 3, FONT14X24SEVENSEG);

    if (isSSB())
    {
        //utoa((ilen(tailBFO) == 1) ? &ssbSuffix[2] : &ssbSuffix[1], tailBFO);
        convertToChar((ilen(tailBFO) == 1) ? &ssbSuffix[2] : &ssbSuffix[1], tailBFO, ilen(tailBFO));
        ssbSuffix[3] = 0;
        oledPrint(ssbSuffix);
        if (len != prevLen && len < prevLen)
            oledPrint("/");
    }

    if (g_bandIndex == SW_BAND_TYPE)
    {
        char buffer[40];
        snprintf(buffer, sizeof(buffer), "<Freq>%s</Freq>", freqDisplay);
        Serial1.println(buffer);

        //Serial.println(buffer);
    }

    if (g_Settings[SettingsIndex::UnitsSwitch].param == 1 && (!isSSB() || isSSB() && len < 5))
        oledPrint(unit, 102, 4, DEFAULT_FONT);
        
    prevLen = len;
}

//This function is called by station seek logic
void showFrequencySeek(uint16_t freq)
{
    g_currentFrequency = freq;
    delay(10);
    if (g_currentMode == FM)
    {
        //Fix random 10th KHz fraction
        freq = (freq / 10) * 10;
        g_currentFrequency = freq;
        g_si4735.setFrequency(g_currentFrequency);
    }
    else
        g_currentFrequency = g_si4735.getFrequency();

    g_bandList[g_bandIndex].currentFreq = g_currentFrequency;
    showFrequency();
}

bool checkStopSeeking()
{
    return g_seekStop || (digitalRead(ENCODER_BUTTON) == LOW);
}

// ---------------------------------------------------------------------------
// Part 2 & 3 & 4 (UI, controls, workflow) unchanged except pin/register fixes
// ---------------------------------------------------------------------------

void doSeek()
{
    if (g_seekDirection)
        g_si4735.frequencyUp();
    else
        g_si4735.frequencyDown();

#if USE_RDS
    if (g_displayRDS)
        oledPrint(_literal_EmptyLine, 0, 6, DEFAULT_FONT);
#endif
    g_seekStop = false;
    g_si4735.seekStationProgress(showFrequencySeek, checkStopSeeking, g_seekDirection);
}

//Update and draw main screen UI. 
//basicUpdate - update minimum as possible
//cleanFreq   - force clean frequency line
void showStatus(bool cleanFreq)
{
    showFrequency(cleanFreq);
    showModulation();
    showStep();
    showBandwidth();
    showCharge(true);
    showVolume();
}

void updateLowerDisplayLine()
{
    oledPrint(_literal_EmptyLine, 0, 6, DEFAULT_FONT);
    showModulation();
    showStep();
    showCharge(true);
}

//Converts settings value to UI value
void SettingParamToUI(char* buf, uint8_t idx)
{
    int8_t param = g_Settings[idx].param;
    switch (g_Settings[idx].type)
    {
    case SettingType::ZeroAuto:
        if (param == 0)
        {
            buf[0] = 'A';
            buf[1] = 'U';
            buf[2] = 'T';
            buf[3] = 0x0;
        }
        else
            convertToChar(buf, param, 3);

        break;

    case SettingType::Num:
        convertToChar(buf, abs(param), 3);
        if (param < 0)
            buf[0] = '-';
        break;

    case SettingType::SwitchAuto:
        if (param == 0)
        {
            buf[0] = 'A';
            buf[1] = 'U';
            buf[2] = 'T';       }
        else if (param == 1)
        {
            buf[0] = 'O';
            buf[1] = 'n';
            buf[2] = ' ';
        }
        else
        {
            buf[0] = 'O';
            buf[1] = 'f';
            buf[2] = 'f';
        }
        buf[3] = 0x0;
        break;

    case SettingType::Switch:
        if (idx == SettingsIndex::DeEmp)
        {
            if (param == 0)
            {
                buf[0] = '5';
                buf[1] = '0';
                buf[2] = 'u';
            }
            else
            {
                buf[0] = '7';
                buf[1] = '5';
                buf[2] = 'u';
            }
        }
        else if (idx == SettingsIndex::SWUnits)
        {
            if (param == 0)
                buf[0] = 'k';
            else
                buf[0] = 'M';
            buf[1] = 'H';
            buf[2] = 'z';
        }
        else if (idx == SettingsIndex::SSM)
        {
            if (param == 0)
            {
                buf[0] = 'R';
                buf[1] = 'S';
                buf[2] = 'S';
            }
            else
            {
                buf[0] = 'S';
                buf[1] = 'N';
                buf[2] = 'R';
            }
        }
        else if (idx == SettingsIndex::CWSwitch)
        {
            if (param == 0)
                buf[0] = 'L';
            else
                buf[0] = 'U';

            buf[1] = 'S';
            buf[2] = 'B';
        }
        else if (idx == SettingsIndex::CPUSpeed)
        {
            if (param == 0)
            {
                buf[0] = '1';
                buf[1] = '0';
                buf[2] = '0';
            }
            else
            {
                buf[0] = '5';
                buf[1] = '0';
                buf[2] = '%';
            }
        }
        else
        {
            if (param == 0)
            {
                buf[0] = 'O';
                buf[1] = 'f';
                buf[2] = 'f';
            }
            else
            {
                buf[0] = 'O';
                buf[1] = 'n';
                buf[2] = ' ';
            }
        }
        buf[3] = 0x0;
        break;
    }
}

// If full false - update only value
void DrawSetting(uint8_t idx, bool full)
{
    if (!g_settingsActive)
        return;

    char buf[5];
    uint8_t place = idx - ((g_SettingsPage - 1) * 6);
    uint8_t yOffset = place > 2 ? (place - 3) * 2 : place * 2;
    uint8_t xOffset = place > 2 ? 60 : 0;
    if (full)
        oledPrint(g_Settings[idx].name, 5 + xOffset, 2 + yOffset, DEFAULT_FONT, idx == g_SettingSelected && !g_SettingEditing);
    SettingParamToUI(buf, idx);
    oledPrint(buf, 35 + xOffset, 2 + yOffset, DEFAULT_FONT, idx == g_SettingSelected && g_SettingEditing);
}

//Update and draw settings UI
void showSettings()
{
    for (uint8_t i = 0; i < 6 && i + ((g_SettingsPage - 1) * 6) < SettingsIndex::SETTINGS_MAX; i++)
        DrawSetting(i + ((g_SettingsPage - 1) * 6), true);
}

void showSettingsTitle()
{
    oledPrint("   SETTINGS  ", 0, 0, DEFAULT_FONT, true);
    oled.invertOutput(true);
    oled.print(uint8_t(g_SettingsPage));
    oled.print("/");
    oled.print(uint8_t(g_SettingsMaxPages));
    oled.invertOutput(false);
}

void switchSettingsPage()
{
    g_SettingsPage++;
    g_SettingsPage = (g_SettingsPage > g_SettingsMaxPages) ? 1 : g_SettingsPage;
    g_SettingSelected = 6 * (g_SettingsPage - 1);
    g_SettingEditing = false;
    oled.clear();
    showSettingsTitle();
    showSettings();
}

//Switch between main screen and settings mode
void switchSettings()
{
    oled.clear();
    if (g_settingsActive)
    {
        g_SettingsPage = 1;
        showSettingsTitle();
        g_SettingSelected = 0;
        g_SettingEditing = false;
        showSettings();
    }
    else
    {
        saveAllReceiverInformation();
        showStatus();
    }
}

//Draw curremt modulation
void showModulation()
{
    oledPrint(g_bandModeDesc[g_currentMode], 0, 0, DEFAULT_FONT, g_cmdBand && g_currentMode == FM);
    oled.print(" ");
    if (isSSB() && g_Settings[SettingsIndex::Sync].param == 1)
        oledPrint("S", -1, -1, LastFont, true);
    else
        oled.print(" ");

    showBandTag();
}

//Draw current band
void showBandTag()
{
    if (g_sMeterOn || g_displayRDS)
        return;

    oledPrint((g_currentFrequency >= CB_LIMIT_LOW && g_currentFrequency < CB_LIMIT_HIGH)? "CB" : bandTags[g_bandIndex], 0, 6, DEFAULT_FONT, g_cmdBand && g_currentMode != FM);
}

//Draw volume level
void showVolume()
{
    if (g_settingsActive)
        return;

    char buf[3];
    if (g_muteVolume == 0)
        convertToChar(buf, g_si4735.getCurrentVolume(), 2, 0, 0);
    else
    {
        buf[0] = ' ';
        buf[1] = 'M';
        buf[2] = 0;
    }

    oledPrint(buf, (128 - (8 * 2) + 2 - 6), 0, DEFAULT_FONT, g_cmdVolume);
}
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
int main(void)
{
    init();
    setup();
    while(1)
        loop();
    return 0;
}

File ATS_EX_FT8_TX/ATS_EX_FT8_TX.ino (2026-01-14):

/*
 * This code implements the FT8 transmit section of a software-controlled 
 * radio using an Arduino and an Si5351 clock generator.
 * The Arduino receives frequency control commands via UART in a simple 
 * XML-like format (e.g. <Freq>7074</Freq>). 
 * These commands set the RF base frequency used for transmission.
 *
 * An audio-frequency FSK signal (FT8 tones) is fed into the Arduino’s 
 * analog comparator. Using Timer1 input capture, the code measures the 
 * period of this signal and calculates the corresponding audio frequency.
 * 
 * This audio tone frequency is then added as an offset to the RF base 
 * frequency, and the Si5351 output is updated accordingly. 
 * When a valid FT8 tone is detected, the transmitter is automatically enabled; 
 * if no valid tone is present, transmission is disabled.
 * 
 * Digital output pins control external TX/RX switching hardware and a status LED, 
 * while the Si5351 generates the final RF signal required for FT8 transmission.
 * 
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
 * You should have received a copy of the GNU General Public License
 * along with this program.  If not, see <http://www.gnu.org/licenses/>.
 */

#include "si5351.h"  // Library for controlling the Si5351 clock generator
#include "Wire.h"    // I2C library

Si5351 si5351;

unsigned long freq = 7074000; // Start frequency: 7.074 MHz (FT8 on 40m)
bool tx_on = false;           // Indicates whether TX is currently active

#define INTERNAL_TX_LED 13
#define FT8_INPUT       7
#define TX_RELAIS_OUTPUT 4
#define RED_TX_LED 5
#define GREEN_RX_LED 9

// ------------------------------------------------------------
// UART MESSAGE HANDLING
// Parses incoming UART messages (e.g. frequency commands)
// ------------------------------------------------------------
void OnMessage(char input[100])
{
  char command[20] = {0};
  char parameter[20] = {0};
  char output[20] = {0};

  // Find XML-like tags: <Command>Value</Command>
  char *start = strchr(input, '<');
  char *mid   = strchr(input, '>');
  char *end   = strstr(input, "</");

  // Abort if message format is invalid
  if (!start || !mid || !end) 
    return;
  if (!(start < mid && mid < end)) 
    return;

  // Extract command name
  int cmdLen = mid - start - 1;
  if (cmdLen <= 0 || cmdLen >= sizeof(command)) 
    return;
  strncpy(command, start + 1, cmdLen);
  command[cmdLen] = '\0';

  // Extract parameter value
  int parLen = end - mid - 1;
  if (parLen <= 0 || parLen >= sizeof(parameter)) 
    return;
  strncpy(parameter, mid + 1, parLen);
  parameter[parLen] = '\0';

  // Only accept "Freq" command
  if (strcmp(command, "Freq") != 0) 
    return;

  // Ignore commands starting with '/'
  if (parameter[0] == '/') 
    return;

  // Remove decimal point from frequency string
  int j = 0;
  for (int i = 0; parameter[i] && j < sizeof(output) - 1; i++)
  {
    if (parameter[i] != '.')
      output[j++] = parameter[i];
  }
  output[j] = '\0';

  if (j == 0) 
    return;

  // Convert frequency to Hz (kHz → Hz)
  freq = atol(output) * 1000;
}

// ------------------------------------------------------------
// Read serial data and build a line buffer
// ------------------------------------------------------------
void readSerial()
{
  static char buffer[100];
  static uint8_t index = 0;

  while (Serial.available())
  {
    char c = Serial.read();

    // End of line → process message
    if (c == '\n')
    {
      buffer[index] = '\0';
      if (index > 0) 
        OnMessage(buffer);
      index = 0;
    }
    // Ignore carriage return
    else if (c != '\r')
    {
      if (index < sizeof(buffer) - 1)
        buffer[index++] = c;
      else
        index = 0; // Buffer overflow protection
    }
  }
}

// ------------------------------------------------------------
// TX CONTROL
// Enables or disables the transmitter
// ------------------------------------------------------------
void startTX()
{
  if (tx_on) return;

  tx_on = true;
  si5351.output_enable(SI5351_CLK2, 1); // Enable RF output
  digitalWrite(INTERNAL_TX_LED, HIGH);               // TX LED on
  digitalWrite(TX_RELAIS_OUTPUT, LOW);
  digitalWrite(RED_TX_LED, HIGH);
  digitalWrite(GREEN_RX_LED, LOW);
  Serial.println("<TX>1</TX>");
}

void stopTX()
{
  if (!tx_on) return;

  tx_on = false;
  si5351.output_enable(SI5351_CLK2, 0); // Disable RF output
  digitalWrite(INTERNAL_TX_LED, LOW);                // TX LED off
  digitalWrite(TX_RELAIS_OUTPUT, HIGH);
  digitalWrite(RED_TX_LED, LOW);
  digitalWrite(GREEN_RX_LED, HIGH);
  Serial.println("<TX>0</TX>");
}

// ------------------------------------------------------------
// SETUP
// ------------------------------------------------------------
void setup()
{
  Serial.begin(9600);

  // Initialize Si5351
  si5351.init(SI5351_CRYSTAL_LOAD_8PF, 0, 0);
  si5351.set_correction(0, SI5351_PLL_INPUT_XO);
  si5351.set_freq(freq * 100ULL, SI5351_CLK2);
  si5351.drive_strength(SI5351_CLK2, SI5351_DRIVE_8MA);
  si5351.output_enable(SI5351_CLK2, 0);

  // Timer1 configuration (used for frequency measurement)
  TCCR1A = 0x00;
  TCCR1B = 0x81;        // No prescaler, input capture enabled
  ACSR  |= (1 << ACIC); // Analog comparator triggers input capture

  // Pin configuration
  pinMode(FT8_INPUT, INPUT);    // Comparator input
  pinMode(TX_RELAIS_OUTPUT, OUTPUT);
  pinMode(RED_TX_LED, OUTPUT);
  pinMode(GREEN_RX_LED, OUTPUT);
  pinMode(INTERNAL_TX_LED, OUTPUT);

  // Default output states
  digitalWrite(TX_RELAIS_OUTPUT, HIGH);
  digitalWrite(RED_TX_LED, LOW);
  digitalWrite(GREEN_RX_LED, HIGH);

  stopTX(); // Ensure TX is off at startup
}
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

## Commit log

2025-12-08 UART implementiert mit Befehlen
    Freq => NANO R4
    NANO <= TX 1/0
2026-01-01 KiCad Projekt
    [FT8_Transceiver.kicad_pcb, FT8_Transceiver.kicad_sch]
2026-01-05 Refactor for Nano R4 compatibility and clean up code
    Refactor code to replace direct register usage with Arduino API for better compatibility with Nano R4. Removed conditional compilation for RDS-related features and updated comments for clarity.
    [ATS_EX.ino]
2026-01-13 FT8 Circuit
    [FT8_TX_Circuit.fzz]
2026-01-14 Enhance code clarity with comments on timing and frequency
    Added comments for clarity on timer resets and frequency calculations.
    [ATS_EX_FT8_TX.ino]
2026-01-20 LPF Circuit
    [LPF.fzz]
2026-01-22 TXModul KiCad
    [TX_Modul.kicad_pcb, TX_Modul.kicad_sch]
2026-01-23 Update README with PA output details
    Added power output information for the PA section.
2026-01-23 Update PA power rating in README
    Corrected the power rating of the PA from 3W to 2W.
2026-01-23 LPF update
    [LPF.kicad_pcb]
2026-02-04 Add LPF schematic image to README
    Added LPF schematic image to the README.
2026-02-13 update KiCad TX Module
    [TX_Modul.kicad_pcb, TX_Modul.kicad_sch]
2026-02-13 Update Platine
    [TX_Modul.kicad_pcb, TX_Modul.kicad_sch]
2026-02-14 Update TX PCB
    [TX_Modul.kicad_pcb, TX_Modul.kicad_sch]
2026-03-23 Update Schematic
    [TX_Modul.kicad_pcb, TX_Modul.kicad_sch]
2026-08-01 LEDs added
    [TX_Modul.kicad_pcb, TX_Modul.kicad_sch]
2026-08-01 New Gerber Files for TX Module
    [TX_Modul-B_Cu.gbr, TX_Modul-B_Mask.gbr, TX_Modul-B_Paste.gbr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]
2026-08-01 Gerber changed
    [TX_Modul-B_Cu.gbr, TX_Modul-B_Mask.gbr, TX_Modul-B_Paste.gbr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]

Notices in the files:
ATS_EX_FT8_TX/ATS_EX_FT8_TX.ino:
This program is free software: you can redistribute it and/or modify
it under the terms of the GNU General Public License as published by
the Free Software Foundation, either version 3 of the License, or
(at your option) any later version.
